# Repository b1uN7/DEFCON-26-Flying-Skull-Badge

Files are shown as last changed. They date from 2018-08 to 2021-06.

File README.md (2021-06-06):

DEFCON 26 Flying Skull Badge

__Let's wotk together for DEFCON 29 (2021)!!  I have set up a new Slack fir us to prepare: 
https://join.slack.com/t/flyingbadgers/shared_invite/zt-rhldgde9-1GLsEr0Yzdh6VICE2oVjuQ__

/------------------------------------------------------------------------------------------------\\ 

| . .  . * READ ME * . . . * NO SHIT READ ME * . . . *You will be F#@KED if you don't READ ME!!!*  . . . |

/------------------------------------------------------------------------------------------------\\ 

|--------------------__I have figured the following items out _the hard way_!!!__-----------------------|

/------------------------------------------------------------------------------------------------\\ 

| 1 DO NOT CROSS NEG & POS -/+ there is no protection for this (ie soldering on battery leads!) 

| 2 DO NOT solder RED FCU Board more then 3 SECS!  Diods will POP & NEED TO BUY NEW ONES!

| 3 If RED FCU Board from Syma 5X is solid RED (no blink) when powered see #2!!

| 4 Propellors are different (A & B) be sure to MATCH them to the MOTORS (See badge around motors!)

/------------------------------------------------------------------------------------------------\\

*** QUICK UPDATE: GETTING STARTED WITH YOU BADGE ***                   

*** (AKA GETTING YOUR BADGE STARTED) VIDEO IS NOW POSTED TO WIKI ***

Ok, so if you are here, you are probably looking for flying badge stuff like "how the f*$K do I put this thing together" or "it won't stop bliking, why won't it stop blinking"

This site (in time) will answer all those questions.

For now, until I can get stuff up on Thursday (I won't commit to which Thursday I am talking about) here are the answers to those questions:

Q1: How to put it together?

A1: If you are a hacker, figure it out!  If you are not a hacker, why the f*%K do you have a hacker badge? 

Q2: How do I get this stupid-ass badge to stop blinking?

A2: See Q1

Ok, only kidding.  If you don't have a sense of humor and you expect everything to be perfect, then "this is not the badge you are looking for" <virtual hand swipe>

If you are here, then you probably know me enough to realize if it took me a year longer to get you your badge, then you will have figured out I am behind on the documentation (*WHAT, you say, I DIDN'T DO THE DOCUMENTATION FIRST OR ALONG THE WAY???  WTF???)

So be patient and lets work together.  I will be using this repository's wiki to post a lot of the stuff you are looking for (build instructions, videos, my home address so you can come kick me in the balls for making this stupid badge, etc).  As we are a hacker community, it would be great if we worked together and post all our combined shit there!  PLEASE be and ACTIVE part of this process!!  I encourage you to post, advise, answer, and collectively curse at me for doing this to you!!

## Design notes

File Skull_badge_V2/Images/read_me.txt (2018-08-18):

Place 3D renders of the PCB and other images here

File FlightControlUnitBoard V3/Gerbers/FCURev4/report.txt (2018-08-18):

Info: Front side (top side) place file: "/Users/rscote/Dropbox/DC26/FlyingSkull/gitlab/FlightControlUnitBoard V3/Gerbers/FCURev4/FlightControlUnitBoard-top.pos".
Info: Component count: 4.
Info: Back side (bottom side) place file: "/Users/rscote/Dropbox/DC26/FlyingSkull/gitlab/FlightControlUnitBoard V3/Gerbers/FCURev4/FlightControlUnitBoard-bottom.pos".
Info: Component count: 4.
Info: Full component count: 8

Component Placement File generation OK.

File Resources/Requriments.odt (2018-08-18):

So here is a summary of what we talked about today:

Requirements:

1) AVR so mini or pro, what ever you think will work best

2) must have USB port for plug and play/programming with arduino

3) Need to dedicate a pin for each of the following:

- LEDs (one pin) for ws2812b RGB LEDS

- Sound (one pin to piezo)

- One pin with voltage divider for monitoring battery

- 6 buttons, one pin, with a series of resisters to analog read to determine button pushed

Header Pins for normal UNO for shields (8&6 and 8&10)

- 10 pin header socket for flight control board

- 10 pin header socket for LCD

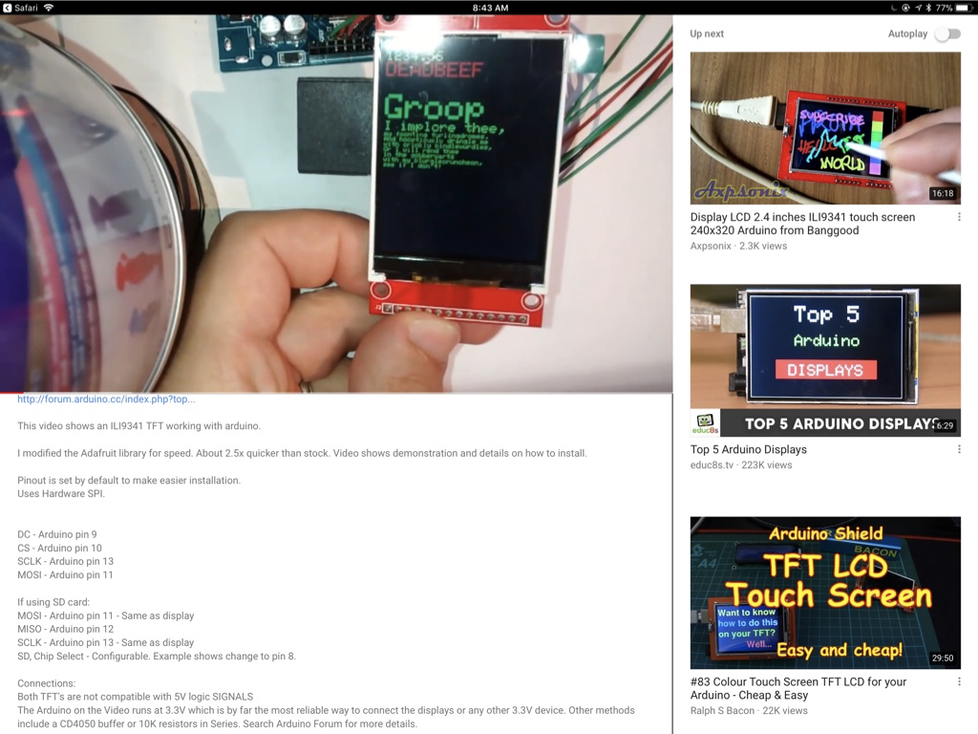
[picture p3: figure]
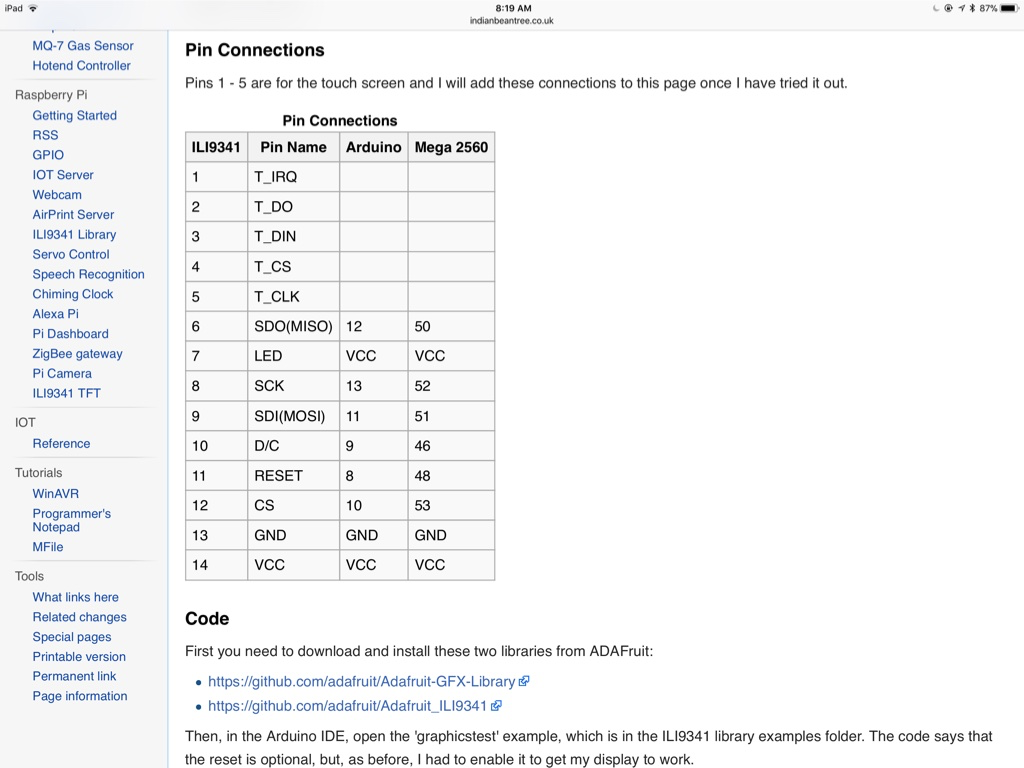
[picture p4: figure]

I will be swapping pins on LCD to the front side for mounting from behind on the skull badge, so we need to pay special attention to the pin order

battery will be a 2S LIPO so approx 8.5 v

switch to turn off Vin to badge, but NOT to the flight control header pins (so the user can turn off the lights and sound, but still fly; Vin should split and go to the switch to the voltage regulators and Vin header socket for flight control)

************************************************************

for information on the RGB LEDS see the sheet from this years attempt of mine at redoing the badge, will have sheets on them and the sound

as well as the flight control sockets

the LCD socket is new

Arduino socket libs: https://github.com/Alarm-Siren/arduino-kicad-library

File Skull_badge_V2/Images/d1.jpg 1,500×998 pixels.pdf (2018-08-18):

d1.jpg 1,500×998 pixels.pdf (https://s3.amazonaws.com/fiverr.com/message_attachements/539292386/original/d1.jpg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)
Saved to Dropbox • Jun 17, 2018 at 8B02 AM

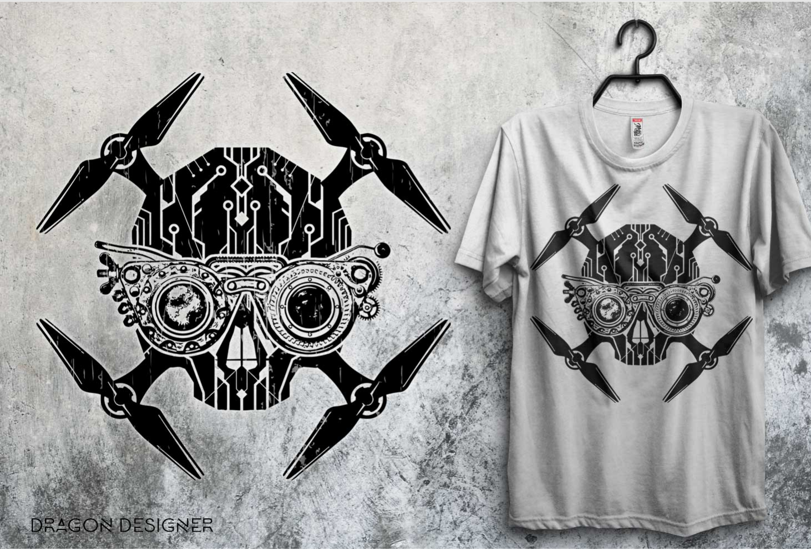
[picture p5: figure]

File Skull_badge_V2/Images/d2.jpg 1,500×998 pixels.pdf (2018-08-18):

d2.jpg 1,500×998 pixels.pdf (https://s3.amazonaws.com/fiverr.com/message_attachements/539292387/original/d2.jpg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)
Saved to Dropbox • Jun 17, 2018 at 8B02 AM

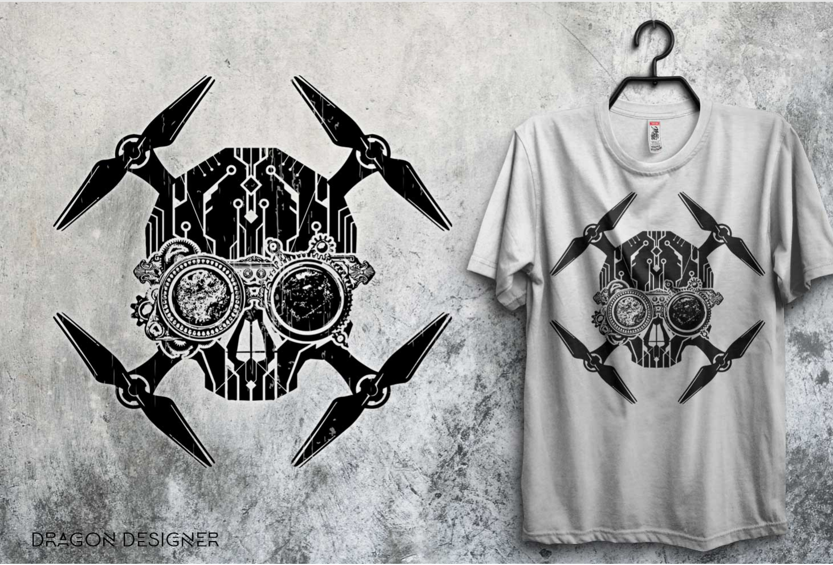
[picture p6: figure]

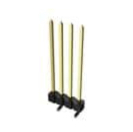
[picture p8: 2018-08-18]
Addon_board/images/95293-101-10LF Amphenol FCI Mouser 2018-07-03 07-41-04.jpg

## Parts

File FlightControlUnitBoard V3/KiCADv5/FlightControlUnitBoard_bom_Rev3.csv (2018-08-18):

Component | Description | Part | References | Value | Footprint | Quantity Per PCB | Datasheet
1 | LED generic | LED | D1 D4 | GREEN | LED_0805 | 2
2 | LED generic | LED | D2 D3 | RED | LED_0805 | 2
3 | Generic connector, single row, 01x02 | Conn_01x02_Male | J2 J3 J4 J5 J6 | Conn_01x02_Male | Wire_Pads_1x2_4x3mm | 5
4 | Generic connector, double row, 02x01, this symbol is compatible with counter-clockwise, top-bottom and odd-even numbering schemes. | Conn_02x01 | J10 J11 | Conn_02x01 | SMD_Pads_1x2 | 2
5 | Generic connector, double row, 02x01, this symbol is compatible with counter-clockwise, top-bottom and odd-even numbering schemes. | Conn_02x01 | J7 J8 J9 | Conn_02x01 | Pin_Header_Straight_1x02_Pitch2.54mm | 3
6 | Generic connector, double row, 02x05, odd/even pin numbering scheme (row 1 odd numbers, row 2 even numbers) | Conn_02x05_Odd_Even | J1 | Conn_02x05_Odd_Even | Pin_Header_Straight_2x05_Pitch2.54mm | 1
7 | Resistor | R | R1 R2 R3 R4 | 33 | R_0805 | 4
Component Groups: | 7
Component Count: | 19
Fitted Components: | 19
Number of PCBs: | 1
Total components: | 19
Schematic Version: | 0
Schematic Date: | 4/24/18
BoM Date: | Friday, June 29, 2018 'PMt' 12:47:06 PM
Schematic Source: | /Users/rscote/Dropbox/DC26/FlyingSkull/gitlab/FlightControlUnitBoard V3/FlightControlUnitBoard.sch
KiCad Version: | Eeschema 4.0.7

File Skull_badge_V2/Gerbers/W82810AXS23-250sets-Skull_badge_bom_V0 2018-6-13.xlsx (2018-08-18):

Component | Description | Part | References | Value | Footprint | Quantity Per PCB | Datasheet | manf# | 250sets
1 |  | C_Small | C4 C6 C14 C15 C16 C17 C18 C19 C20 C21 C22 C23 C24 C25 C26 C27 C28 C29 C30 | 100nF | C_0805 | 19 |  | Use house parts |  |  | house 0805 capacitors are fine
2 |  | C_Small | C1 C7 C12 C13 | 10uF | C_0805 | 4 |  | Use house parts | $0.055 | $0.220
3 |  | C_Small | C5 C8 C9 C10 C11 | 1uF | C_0805 | 5 |  | Use house parts | $0.055 | $0.275
4 |  | C_Small | C2 C3 | 22pF | C_0805 | 2 |  | Use house parts | $0.009 | $0.018
5 |  | LED | D4 | L | LED_0805 | 1 |  | Use house parts | $0.187 | $0.187
6 |  | LED | D3 | PWR | LED_0805 | 1 |  | Use house parts | $0.187 | $0.187
7 |  | LED | D1 | RX | LED_0805 | 1 |  | Use house parts | $0.187 | $0.187
8 |  | LED | D2 | TX | LED_0805 | 1 |  | Use house parts | $0.187 | $0.187
9 |  | Fuse | F1 | Fuse | Fuse_SMD2920 | 1 |  | 2920L500/16MR | $1.562 | $1.562 | Do you have an equal house part?
10 |  | Conn_01x02 | J4 | BtmL | Wire_Pads_1x2_4x3mm_Extended | 1 |  | Do Not Source, Nothing to Assemble, Leave Empty |  |  | DNS
11 |  | Conn_01x02 | J5 | BtmR | Wire_Pads_1x2_4x3mm_Extended | 1 |  | Do Not Source, Nothing to Assemble, Leave Empty |  |  | DNS
12 |  | Conn_02x05 | J7 | Flight Controller Board | Socket_Strip_Straight_2x05_Pitch2.54mm | 1 |  |  | $0.110 | $0.110 | 2*5pin 2.54mm pls check the pic
13 |  | Conn_01x02 | J2 | LiPo | JST_PH_S2B-PH-K_02x2.00mm_Angled | 1 |  | IF you cannot find a PCB mount option then DNS | $0.088 | $0.088 | ~~S2B-PH-K-S(LF)(SN)~~ | LOSI Female PCB Mount | 51005-Micro-losi-connecto
14 |  | Conn_01x03 | J8 | SPI | Pin_Header_Straight_1x03_Pitch2.54mm | 1 |  |  | $0.022 | $0.022 | pin header 1*3pin 2.54mm
15 |  | Conn_01x02 | J6 | TopL | Wire_Pads_1x2_4x3mm_Extended | 1 |  | Do Not Source, Nothing to Assemble, Leave Empty |  |  | DNS
16 |  | Conn_01x02 | J3 | TopR | Wire_Pads_1x2_4x3mm_Extended | 1 |  | Do Not Source, Nothing to Assemble, Leave Empty |  |  | DNS
17 |  | USB_OTG | J1 | USB_OTG | USB_Micro-B_10103594-0001LF | 1 |  | 10103594-0001LF | $0.462 | $0.462
18 |  | L | L2 | 2.2uH | VLF4012A | 1 |  | VLF4012AT-2R2M1R5 | $0.385 | $0.385
19 |  | L | L1 | L | L_0805 | 1 |  | BLM21AG601SN1D | $0.033 | $0.033
20 |  | Speaker_Crystal | LS1 | piezo_KJL_1325 | https://lcsc.com/product-detail/Buzzers_KELIKING-KLJ-1325_C201043.html | 1 |  | https://datasheet.lcsc.com/szlcsc/KELIKING-KLJ-1325_C201043.pdf | $0.590 | $0.590 | http://www.keliking.com/KLJ-1325-SMD-Piezo-Buzzer-pd6794765.html
21 |  | R | R5 | 100 | R_0805 | 1 |  | Use house parts | $0.009 | $0.009
22 |  | R | R3 R6 | 10K | R_0805 | 2 |  | Use house parts | $0.009 | $0.018
23 |  | R | R7 R8 R9 R12 R13 R14 R15 R16 R17 R18 R19 | 1K | R_0805 | 11 |  | Use house parts | $0.009 | $0.097
24 |  | R | R4 R10 R20 | 1M | R_0805 | 3 |  | Use house parts | $0.009 | $0.026
25 |  | R | R1 R2 | 22 | R_0805 | 2 |  | Use house parts | $0.009 | $0.018
26 |  | R | R11 | 2M | R_0805 | 1 |  | Use house parts | $0.009 | $0.009
27 |  | R | R21 | 300 | R_0805 | 1 |  | RC0805JR-07300RL | $0.009 | $0.009
28 |  | SW_SPDT | SW2 | ARD_SW | switch_MSK-12D19 | 1 |  | MSK-12D19 | $0.050 | $0.050 | Aliexpress $0.05/ea https://www.aliexpress.com/item/FREE-SHIPPING-100pcs-lot-MSK-12D19-1P2T-3PIN-toggle-switch-micro-switch-slide-switch/32770997921.html
29 |  | SW_SPDT | SW3 | FLT CTRL SW | switch_MSK-12D19 | 1 |  | MSK-12D19 | $0.050 | $0.050 | Aliexpress $0.05/ea https://www.aliexpress.com/item/FREE-SHIPPING-100pcs-lot-MSK-12D19-1P2T-3PIN-toggle-switch-micro-switch-slide-switch/32770997921.html
30 |  | SW_Push | SW1 | RESET | smd_push | 1 |  |  | $0.030 | $0.030 | Aliexpress $0.0.3/ea https://www.aliexpress.com/item/1000-Pcs-Per-Lot-Momentary-Tactile-Tact-Push-Button-Switch-2-Pin-SMD-SMT-3x6x2-5mm/32261460144.html
31 |  | SW_Push | SW4 SW5 SW6 SW7 SW8 SW9 | SW_Push | smd_push | 6 |  |  | $0.030 | $0.180 | Aliexpress $0.0.3/ea https://www.aliexpress.com/item/1000-Pcs-Per-Lot-Momentary-Tactile-Tact-Push-Button-Switch-2-Pin-SMD-SMT-3x6x2-5mm/32261460144.html
32 | TQFP44, 16K Flash, 1.25K SRAM, 512B EEPROM, USB2.0 | ATMEGA32U4-AU | U1 | ATMEGA32U4-AU | TQFP-44_10x10mm_Pitch0.8mm | 1 | http://www.atmel.com/images/atmel-7766-8-bit-avr-atmega16u4-32u4_%20datasheet.pdf | ATMEGA32U4-AUR | $3.520 | $3.520
33 |  | TPS63001 | U2 | TPS63001 | VSON-10-1EP_3x3mm_Pitch0.5mm_ThermalPad | 1 |  | TPS63002DRCT | $1.430 | $1.430
34 |  | WS2812B | U9 U10 U11 U12 U13 U14 U15 U16 U17 U18 U19 U20 U21 U22 U23 U24 | WS2812B | LED_WS2812B-PLCC4 | 16 |  | 1655 | $0.060 | $0.968 | aliexpress: $.06/ea https://www.aliexpress.com/item/WS2812B-4pins-5050-SMD-W-WS2811-Individually-Addressable-Digital-RGB-LED-Chip-5V/1639139960.html
35 |  | Conn_02x02 | X1 | Badgelife_shitty_connector | Socket_Strip_Straight_2x02_Pitch2.54mm | 1 |  |  |  |  | aliexpress $.05/ea https://www.aliexpress.com/item/100pcs-2x2-Pin-2-54mm-Double-Row-Female-Pin-Header-4P-PCB-Socket-Connector/32604467904.html
36 |  | Conn_01x06 |  | 1x6 socket strip 2.54mm |  | 1 |  |  |  |  | strip for arduino uno socket headers
37 |  | Conn_01x10 |  | 1x10 scoket strip 2.54mm |  | 1 |  |  |  |  | strip for arduino uno socket headers
38 |  | Conn_01x08 |  | 1x8 scoket strip 2.54mm |  | 2 |  |  |  |  | strip for arduino uno socket headers
39 |  | Header Pins 02x03 | XA1 | 2x3 Header Pins 2.54mm |  | 1 |  |  |  |  | ICSP Arduino Uno Header Pins
40 |  | Crystal | Y1 | 16MHz | Q_49U3HMS | 1 |  | ABLS-16.000MHZ-B4-T | $0.220 | $0.220 | Do you have an equal house part?
41 |  | Regulator voltage 3v3 |  | 1117-3v3 |  | 1 |  |  | 1 set | $11.145
 |  |  |  |  |  |  |  |  | 250 sets | $2786.350 | http://www.irf.com/product-info/datasheets/data/iru1117-33.pdf
Component Groups: | 41
Component Count: | 99
Fitted Components: | 99
Number of PCBs: | 1
Total components: | 99
Schematic Version: | V0
Schematic Date: | 5/14/18
BoM Date: | Monday, June 11, 2018 'PMt' 04:22:07 PM
Schematic Source: | /Users/rscote/Dropbox/DC26/FlyingSkull/gitlab/Skull_badge_V2/Skull_badge.sch
KiCad Version: | Eeschema 4.0.7
J7 |  |  | J2
 |  |  |  |  |  | LS1
SW2 SW3
 |  |  | s1,s4,s5,s6,s7,s8,s9

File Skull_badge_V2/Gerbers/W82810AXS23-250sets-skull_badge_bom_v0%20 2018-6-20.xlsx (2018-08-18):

Component | Description | Part | References | Value | Footprint | Quantity Per PCB | Datasheet | manf# |  |  |  | 250sets
1 |  | C_Small | C4 C6 C14 C15 C16 C17 C18 C19 C20 C21 C22 C23 C24 C25 C26 C27 C28 C29 C30 | 100nF | C_0805 | 19 |  | Use house parts | house 0805 capacitors are fine |  |  | $0.033 | $0.627
2 |  | C_Small | C1 C7 C12 C13 | 10uF | C_0805 | 4 |  | Use house parts |  |  |  | $0.055 | $0.220
3 |  | C_Small | C5 C8 C9 C10 C11 | 1uF | C_0805 | 5 |  | Use house parts |  |  |  | $0.055 | $0.275
4 |  | C_Small | C2 C3 | 22pF | C_0805 | 2 |  | Use house parts |  |  |  | $0.009 | $0.018
5 |  | LED 0805 GREEN | D4 | L | LED_0805 | 1 |  | Use house parts |  |  |  | $0.187 | $0.187 | 5-7work days
6 |  | LED 0805 BLUE | D3 | PWR | LED_0805 | 1 |  | Use house parts |  |  |  | $0.187 | $0.187 | 5-7work days
7 |  | LED 0805 WHITE | D1 | RX | LED_0805 | 1 |  | Use house parts |  |  |  | $0.187 | $0.187 | 5-7work days
8 |  | LED 0805 WHITE | D2 | TX | LED_0805 | 1 |  | Use house parts |  |  |  | $0.187 | $0.187 | 5-7work days
9 |  | Fuse | F1 | Fuse | Fuse_SMD2920 | 1 |  | 2920L500/16MR | Do you have an equal house part? |  |  | $0.385 | $0.385 | Made in China
10 |  | Conn_01x02 | J4 | BtmL | Wire_Pads_1x2_4x3mm_Extended | 1 |  | Do Not Source, Nothing to Assemble, Leave Empty | DNS
11 |  | Conn_01x02 | J5 | BtmR | Wire_Pads_1x2_4x3mm_Extended | 1 |  | Do Not Source, Nothing to Assemble, Leave Empty | DNS
12 |  | Conn_02x05 | J7 | Flight Controller Board | Socket_Strip_Straight_2x05_Pitch2.54mm | 1 |  |  | 2*5pin 2.54mm pls check the pic |  |  | $0.110 | $0.110 | 2*5pin 2.54mm pls check the pic
13 |  | Conn_01x02 | J2 | LiPo | JST_PH_S2B-PH-K_02x2.00mm_Angled | 1 |  | Do Not Source, Nothing to Assemble, Leave Empty | DNS | LOSI Female PCB Mount | 51005-Micro-losi-connecto
14 |  | Conn_01x03 | J8 | SPI | Pin_Header_Straight_1x03_Pitch2.54mm | 1 |  |  | pin header 1*3pin 2.54mm |  |  | $0.022 | $0.022 | pin header 1*3pin 2.54mm
15 |  | Conn_01x02 | J6 | TopL | Wire_Pads_1x2_4x3mm_Extended | 1 |  | Do Not Source, Nothing to Assemble, Leave Empty | DNS
16 |  | Conn_01x02 | J3 | TopR | Wire_Pads_1x2_4x3mm_Extended | 1 |  | Do Not Source, Nothing to Assemble, Leave Empty | DNS
17 |  | USB_OTG | J1 | USB_OTG | USB_Micro-B_10103594-0001LF | 1 |  | 10103594-0001LF |  |  |  | $0.462 | $0.462
18 |  | L | L2 | 2.2uH | VLF4012A | 1 |  | VLF4012AT-2R2M1R5 |  |  |  | $0.385 | $0.385
19 |  | L | L1 | L | L_0805 | 1 |  | BLM21AG601SN1D |  |  |  | $0.033 | $0.033
20 |  | Speaker_Crystal | LS1 | piezo_KJL_1325 | https://lcsc.com/product-detail/Buzzers_KELIKING-KLJ-1325_C201043.html | 1 |  | https://datasheet.lcsc.com/szlcsc/KELIKING-KLJ-1325_C201043.pdf | http://www.keliking.com/KLJ-1325-SMD-Piezo-Buzzer-pd6794765.html |  |  | $0.770 | $0.770 | KLJ-1325 SMD 1 week order time
21 |  | R | R5 | 100 | R_0805 | 1 |  | Use house parts |  |  |  | $0.009 | $0.009
22 |  | R | R3 R6 | 10K | R_0805 | 2 |  | Use house parts |  |  |  | $0.009 | $0.018
23 |  | R | R7 R8 R9 R12 R13 R14 R15 R16 R17 R18 R19 | 1K | R_0805 | 11 |  | Use house parts |  |  |  | $0.009 | $0.097
24 |  | R | R4 R10 R20 | 1M | R_0805 | 3 |  | Use house parts |  |  |  | $0.009 | $0.026
25 |  | R | R1 R2 | 22 | R_0805 | 2 |  | Use house parts |  |  |  | $0.009 | $0.018
26 |  | R | R11 | 2M | R_0805 | 1 |  | Use house parts |  |  |  | $0.009 | $0.009
27 |  | R | R21 | 300 | R_0805 | 1 |  | RC0805JR-07300RL |  |  |  | $0.009 | $0.009
28 |  | SW_SPDT | SW2 | ARD_SW | SW_SPDT_PCM12 | 1 |  | MSK-12C02 | Aliexpress $0.03/ea https://www.aliexpress.com/item/50Pcs-Mini-7-Pin-On-Off-1P2T-SPDT-MSK-12C02-SMD-Toggle-Slide-Switch-For-MP3/32839604589.html |  |  | $0.030 | $0.030 | Made in China, MSK-12D19
30 |  | SW_Push | SW1 | RESET | smd_push | 1 |  |  | Aliexpress $0.0.3/ea https://www.aliexpress.com/item/1000-Pcs-Per-Lot-Momentary-Tactile-Tact-Push-Button-Switch-2-Pin-SMD-SMT-3x6x2-5mm/32261460144.html |  |  | $0.033 | $0.033 | Made in China
31 |  | SW_Push | SW4 SW5 SW6 SW7 SW8 SW9 | SW_Push | smd_push | 6 |  |  | Aliexpress $0.0.3/ea https://www.aliexpress.com/item/1000-Pcs-Per-Lot-Momentary-Tactile-Tact-Push-Button-Switch-2-Pin-SMD-SMT-3x6x2-5mm/32261460144.html |  |  | $0.033 | $0.198 | Made in China
32 | TQFP44, 16K Flash, 1.25K SRAM, 512B EEPROM, USB2.0 | ATMEGA32U4-AU | U1 | ATMEGA32U4-AU | TQFP-44_10x10mm_Pitch0.8mm | 1 | http://www.atmel.com/images/atmel-7766-8-bit-avr-atmega16u4-32u4_%20datasheet.pdf | ATMEGA32U4-AUR |  |  |  | $3.520 | $3.520
33 |  | TPS63001 | U2 | TPS63001 | VSON-10-1EP_3x3mm_Pitch0.5mm_ThermalPad | 1 |  | TPS63002DRCT |  |  |  | $1.430 | $1.430
34 |  | WS2812B | U9 U10 U11 U12 U13 U14 U15 U16 U17 U18 U19 U20 U21 U22 U23 U24 | WS2812B | LED_WS2812B-PLCC4 | 16 |  | 1655 | aliexpress: $.06/ea https://www.aliexpress.com/item/WS2812B-4pins-5050-SMD-W-WS2811-Individually-Addressable-Digital-RGB-LED-Chip-5V/1639139960.html |  |  | $0.110 | $1.760 | WS2812B SMD4 size 5050 | 贴片前75度 除湿48小时，焊接温度不超过250摄氏度-徐冰雪购买
35 |  | Conn_02x02 | X1 | Badgelife_shitty_connector | Socket_Strip_Straight_2x02_Pitch2.54mm | 1 |  |  | aliexpress $.05/ea https://www.aliexpress.com/item/100pcs-2x2-Pin-2-54mm-Double-Row-Female-Pin-Header-4P-PCB-Socket-Connector/32604467904.html |  |  | $0.066 | $0.066 | pin female 2*2pin 2.54mm height 8.5mm
36 |  | Conn_01x06 |  | 1x6 socket strip 2.54mm |  | 1 |  |  | strip for arduino uno socket headers |  |  | $0.022 | $0.022 | pin header 1*6pin 2.54mm
37 |  | Conn_01x10 |  | 1x10 scoket strip 2.54mm |  | 1 |  |  | strip for arduino uno socket headers |  |  | $0.033 | $0.033 | pin header 1*10pin 2.54mm
38 |  | Conn_01x08 |  | 1x8 scoket strip 2.54mm |  | 2 |  |  | strip for arduino uno socket headers |  |  | $0.033 | $0.066 | pin header 1*8pin 2.54mm
39 |  | Header Pins 02x03 | XA1 | 2x3 Header Pins 2.54mm |  | 1 |  |  | DNS |  |  | $0.033 | $0.033 | pin header 2*3pin 2.54mm
40 |  | Crystal | Y1 | 16MHz | Q_49U3HMS | 1 |  | ABLS-16.000MHZ-B4-T | Do you have an equal house part? |  |  | $0.088 | $0.088 | Made in China
41 |  | Regulator voltage 3v3 |  | 1117-3v3 |  | 1 |  |  |  |  |  | $0.099 | $0.099 | offer is AMS1117-3.3 SOT223
 |  |  |  |  |  |  |  |  | http://www.irf.com/product-info/datasheets/data/iru1117-33.pdf |  |  | 1 set | $11.62
 |  |  |  |  |  |  |  |  |  |  |  | 300 sets | $3485.22
Component Groups: | 41
Component Count: | 99
Fitted Components: | 99
Number of PCBs: | 1
Total components: | 99
Schematic Version: | V0
Schematic Date: | 5/14/18
BoM Date: | Monday, June 11, 2018 'PMt' 04:22:07 PM
Schematic Source: | /Users/rscote/Dropbox/DC26/FlyingSkull/gitlab/Skull_badge_V2/Skull_badge.sch
KiCad Version: | Eeschema 4.0.7
J7
 |  |  |  |  |  | LS1
SW2
 |  |  | s1,s4,s5,s6,s7,s8,s9

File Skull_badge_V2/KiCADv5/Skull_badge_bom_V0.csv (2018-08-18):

Component | Description | Part | References | Value | Footprint | Quantity Per PCB | Datasheet | manf#
1 |  | C_Small | C4 C6 C14 C15 C16 C17 C18 C19 C20 C21 C22 C23 C24 C25 C26 C27 C28 C29 C30 | 100nF | C_0805 | 19 |  | 885012207053 885012207060 885012207049 885012207045 885012207056 885012207046 885012207050 885012207057 885012207047 885012207051 885012207054 885012207058 885012207048 885012207052 885012207055 885012207059
2 |  | C_Small | C1 C7 C12 C13 | 10uF | C_0805 | 4
3 |  | C_Small | C5 C8 C9 C10 C11 | 1uF | C_0805 | 5
4 |  | C_Small | C2 C3 | 22pF | C_0805 | 2
5 |  | LED | D4 | L | LED_0805 | 1 |  | 150080YS75000
6 |  | LED | D3 | PWR | LED_0805 | 1 |  | 150080YS75000
7 |  | LED | D1 | RX | LED_0805 | 1 |  | 150080YS75000
8 |  | LED | D2 | TX | LED_0805 | 1 |  | 150080YS75000
9 |  | Fuse | F1 | Fuse | Fuse_SMD2920 | 1 |  | 2920L500/16MR
10 |  | Conn_01x02 | J4 | BtmL | Wire_Pads_1x2_4x3mm_Extended | 1
11 |  | Conn_01x02 | J5 | BtmR | Wire_Pads_1x2_4x3mm_Extended | 1
12 |  | Conn_02x05 | J7 | Flight Controller Board | Socket_Strip_Straight_2x05_Pitch2.54mm | 1
13 |  | Conn_01x02 | J2 | LiPo | JST_PH_S2B-PH-K_02x2.00mm_Angled | 1
14 |  | Conn_01x03 | J8 | SPI | Pin_Header_Straight_1x03_Pitch2.54mm | 1
15 |  | Conn_01x02 | J6 | TopL | Wire_Pads_1x2_4x3mm_Extended | 1
16 |  | Conn_01x02 | J3 | TopR | Wire_Pads_1x2_4x3mm_Extended | 1
17 |  | USB_OTG | J1 | USB_OTG | USB_Micro-B_10103594-0001LF | 1 |  | 10103594-0001LF
18 |  | L | L2 | 2.2uH | VLF4012A | 1 |  | VLF4012AT-2R2M1R5
19 |  | L | L1 | L | L_0805 | 1 |  | BLM21AG601SN1D
20 |  | Speaker_Crystal | LS1 | Speaker_Crystal | piezo_KJL_1325 | 1 |  | KLJ-1325
21 |  | R | R5 | 100 | R_0805 | 1
22 |  | R | R3 R6 | 10K | R_0805 | 2
23 |  | R | R7 R8 R9 R12 R13 R14 R15 R16 R17 R18 R19 | 1K | R_0805 | 11
24 |  | R | R4 R10 R20 | 1M | R_0805 | 3
25 |  | R | R1 R2 | 22 | R_0805 | 2
26 |  | R | R11 | 2M | R_0805 | 1
27 |  | R | R21 | 300 | R_0805 | 1 |  | RC0805JR-07300RL
28 |  | SW_SPDT | SW2 | ARD_SW | switch_MHSS1105 | 1 |  | MHSS1105
29 |  | SW_SPDT | SW3 | FLT CTRL SW | switch_MHSS1105 | 1 |  | MHSS1105
30 |  | SW_Push | SW1 | RESET | smd_push | 1 |  | MJTP1106STR
31 |  | SW_Push | SW4 SW5 SW6 SW7 SW8 SW9 | SW_Push | smd_push | 6 |  | MJTP1106STR
32 | TQFP44, 16K Flash, 1.25K SRAM, 512B EEPROM, USB2.0 | ATMEGA32U4-AU | U1 | ATMEGA32U4-AU | TQFP-44_10x10mm_Pitch0.8mm | 1 | http://www.atmel.com/images/atmel-7766-8-bit-avr-atmega16u4-32u4_%20datasheet.pdf | ATMEGA32U4-AUR
33 |  | TPS63001 | U2 | TPS63001 | VSON-10-1EP_3x3mm_Pitch0.5mm_ThermalPad | 1 |  | TPS63002DRCT
34 |  | WS2812B | U9 U10 U11 U12 U13 U14 U15 U16 U17 U18 U19 U20 U21 U22 U23 U24 | WS2812B | LED_WS2812B-PLCC4 | 16 |  | 1655
35 |  | Conn_02x02 | X1 | Badgelife_shitty_connector | Socket_Strip_Straight_2x02_Pitch2.54mm | 1
36 |  | Arduino_Uno_Shield | XA1 | Arduino_Uno_Shield | UNO_headersICSP: (2) Socket_Strip 1x08, (1) Socket_Strip 1x06, (1) Socket_Strip 1x10, (1) Header_Pins 02x03 | 1
37 |  | Crystal | Y1 | 16MHz | Q_49U3HMS | 1 |  | ABLS-16.000MHZ-B4-T
Component Groups: | 39
Component Count: | 99
Fitted Components: | 99
Number of PCBs: | 1
Total components: | 99
Schematic Version: | V0
Schematic Date: | 5/14/18
BoM Date: | Monday, June 11, 2018 'PMt' 04:22:07 PM
Schematic Source: | /Users/rscote/Dropbox/DC26/FlyingSkull/gitlab/Skull_badge_V2/Skull_badge.sch
KiCad Version: | Eeschema 4.0.7

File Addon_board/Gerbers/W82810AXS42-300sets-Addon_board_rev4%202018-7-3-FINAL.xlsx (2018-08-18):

Id | Designator | Package | Quantity | Designation | Supplier and ref |  | 300sets
1 | C5 | C_0805 | 1 | 10 pF |  |  |  |  | offer the parameter
2 | J1 | Pin_Header_Straight_1x03_Pitch2.54mm | 1 | SPI |  |  | $0.022 | $0.022 | pin header 1*3pin 2.54mm
3 | C6,C7 | C_0805 | 2 | 0.1uF |  |  | $0.033 | $0.066
4 | D1 | LED_0805 | 1 | LED |  |  | $0.022 | $0.022 | LED 0805 green,made in China
5 | R1,R2,R5,R6 | R_0805 | 4 | 10K |  |  | $0.009 | $0.035
6 | R3 | R_0805 | 1 | 1K |  |  | $0.009 | $0.009
7 | R4 | R_0805 | 1 | 2K |  |  | $0.009 | $0.009
8 | U4 | SOIC-8_3.9x4.9mm_Pitch1.27mm | 1 | 24LC256 |  |  | $0.352 | $0.352 | complete part number is 24LC256T-I/SN
9 | U5 | TSSOP-20_4.4x6.5mm_Pitch0.65mm | 1 | TXB0108PWR |  |  | $0.792 | $0.792
10 | U2 | DCDC_BOOST | 1 | DD06AJSA |  |  |  |  | DNS
16 | J4 | SolderJumper | 1 | GS2 | DNS |  |  |  | DNS
17 | SW1,SW2,SW3 | MSK12C02 | 3 | SW_SPDT |  |  | $0.044 | $0.132 | MSK-12C02,made in China
19 | XA2 | UNO_headersICSP_EDIT_10smd | 1 | Shield |  |  |  |  | PARTS LISTED BELOW spreadsheet lines 15-18
 | XA2 Parts
 | X2A - 1X6 | 1x6_Long_pin_Stackable_header Socket | 1 |  |  |  | $0.022 | $0.022 | pin header 1*6pin 2.54mm | MUST BE LONG PIN STACKABLE
 | X2A-1X8 | 1x8_Long_pin_Stackable_header Socket | 2 |  |  |  | $0.022 | $0.044 | pin header 1*8pin 2.54mm | MUST BE LONG PIN STACKABLE
 | X2A 1X10 | 1x10_SMD_header Socket | 1 |  |  |  | $0.033 | $0.033 | pin header 1*10pin 2.54mm | MUST BE LONG PIN STACKABLE
 | J2 | 1x10_SMD_Long_Header_Pins | 1 | pn 95293-101-10LF mouser has them in stock IM 1X10 |  |  | $1.947 | $0.900 | 95293-101-10LF 1*10 PIN LONG 5-7work days | CAN BE CHINESE MADE IF YOU CAN SOURCE SMD LONG PIN HEADERS
 |  |  |  |  |  |  | 1 set | $2.438
 |  |  |  |  |  |  | 300 sets | $731.34
 | X2A - 1X6, 1x8, LONG PINS |  | X2A 1X10 SMD |  |  | J2

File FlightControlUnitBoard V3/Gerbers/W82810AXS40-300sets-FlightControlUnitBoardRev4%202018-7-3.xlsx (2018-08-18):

Id | Designator | Package | Quantity | Designation | Supplier and ref | 300sets
1 | LED1,LED4 | LED_0805 | 2 | GREEN |  | $0.022 | $0.044 | LED 0805 green,made in China
2 | R1,R4 | R_0805 | 2 | 33 |  | $0.009 | $0.018
3 | LED2,LED3 | LED_0805 | 2 | RED |  | $0.022 | $0.044 | LED 0805 red,made in China
4 | R2,R3 | R_0805 | 2 | 47 |  | $0.009 | $0.018
5 | J10,J11 | Pin_Header_Straight_1x02 | 2 | Pin_Header_Straight_1x02 |  | $0.011 | $0.022 | pin heade 1*2pin 2.54m
10 | J5,J6,J2,J4,J3,J2,J3,J4,J5,J6 | Wire_Pads_1x2_4x3mm | 10 | Conn_01x02_Male | DNS
11 | J1 | Pin_Header_Straight_2x05_Pitch2.54mm | 1 | Conn_02x05_Odd_Even |  | $0.044 | $0.044 | pin header 2*5pin 2.54mm
12 | J9,J8,J7 | Pin_Header_Straight_1x02_Pitch2.54mm | 3 | Conn_02x01 |  | $0.011 | $0.033 | pin header 1*2pin 2.54m
 |  |  |  |  |  | 1 set | $0.222
 |  |  |  |  |  | 300 sets | $66.66

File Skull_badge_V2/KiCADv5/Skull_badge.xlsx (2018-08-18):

 |  |  |  |  |  |  | Board Qty: | 100
 |  |  |  |  |  |  | Total Cost: | $748.16 |  |  |  | $748.16
 |  |  |  |  |  |  | Unit Cost: | $7.48
Global Part Info |  |  |  |  |  |  |  |  | Digi-Key
Refs | Value | Desc | Footprint | Manf | Manf# | Qty | Unit$ | Ext$ | Avail | Purch | Unit$ | Ext$ | Cat# | Doc
D4 | L |  | Skull_badge:LED_0805 |  | 150080YS75000 | 100 | $0.14 | $13.70 | 11297 |  | $0.14 | $13.70 | 732-4987-1-ND | Link (http://www.digikey.com/product-detail/en/wurth-electronics-inc/150080YS75000/732-4987-1-ND/4489925)
J5 | BtmR |  | Skull_badge:Wire_Pads_1x2_4x3mm_Extended |  |  | 100 | $0.00 | $0.00
U9-U24 | WS2812B |  | Skull_badge:LED_WS2812B-PLCC4 |  | 1655 | 1600 | $0.00 | $0.00
R1,R2 | 22 |  | Skull_badge:R_0805 |  |  | 200 | $0.00 | $0.00
R21 | 300 |  | Skull_badge:R_0805 |  | RC0805JR-07300RL | 100 | $0.01 | $0.76 | 95913 |  | $0.01 | $0.76 | 311-300ARCT-ND | Link (http://www.digikey.com/product-detail/en/yageo/RC0805JR-07300RL/311-300ARCT-ND/731254)
J4 | BtmL |  | Skull_badge:Wire_Pads_1x2_4x3mm_Extended |  |  | 100 | $0.00 | $0.00
U1 | ATMEGA32U4-AU |  | Skull_badge:TQFP-44_10x10mm_Pitch0.8mm |  | ATMEGA32U4-AUR | 100 | $3.49 | $349.17 | 13471 |  | $3.49 | $349.17 | ATMEGA32U4-AURCT-ND | Link (http://www.digikey.com/product-detail/en/microchip-technology/ATMEGA32U4-AUR/ATMEGA32U4-AURCT-ND/3440960)
C2,C3 | 22pF |  | Skull_badge:C_0805 |  |  | 200 | $0.00 | $0.00
J8 | SPI |  | Pin_Headers:Pin_Header_Straight_1x03_Pitch2.54mm |  |  | 100 | $0.00 | $0.00
SW1 | RESET |  | Skull_badge:smd_push |  | MJTP1106STR | 100 | $0.51 | $51.06 | 10429 |  | $0.51 | $51.06 | 679-2395-1-ND | Link (http://www.digikey.com/product-detail/en/apem-inc/MJTP1106STR/679-2395-1-ND/2344159)
J2 | LiPo |  | Skull_badge:JST_PH_S2B-PH-K_02x2.00mm_Angled |  |  | 100 | $0.00 | $0.00
R7-R9,R12-R19 | 1K |  | Skull_badge:R_0805 |  |  | 1100 | $0.00 | $0.00
SW3 | FLT CTRL SW |  | Skull_badge:switch_MHSS1105 |  | MHSS1105 | 100 | $0.43 | $42.80 | 18880 |  | $0.43 | $42.80 | 679-1849-ND | Link (http://www.digikey.com/product-detail/en/apem-inc/MHSS1105/679-1849-ND/1949465)
U6 | Lime_pepper |  | Skull_badge:lime_pepper |  |  | 100 | $0.00 | $0.00
LS1 | Speaker_Crystal |  | Skull_badge:piezo_KJL_1325 |  | KLJ-1325 | 100 | $0.00 | $0.00
C4,C6 | 100nF |  | Skull_badge:C_0805 |  |  | 200 | $0.00 | $0.00
D1 | RX |  | Skull_badge:LED_0805 |  | 150080YS75000 | 100 | $0.14 | $13.70 | 11297 |  | $0.14 | $13.70 | 732-4987-1-ND | Link (http://www.digikey.com/product-detail/en/wurth-electronics-inc/150080YS75000/732-4987-1-ND/4489925)
L2 | 2.2uH |  | Skull_badge:VLF4012A |  | VLF4012AT-2R2M1R5 | 100 | $0.52 | $51.75 | 48078 |  | $0.52 | $51.75 | 445-3233-1-ND | Link (http://www.digikey.com/product-detail/en/tdk-corporation/VLF4012AT-2R2M1R5/445-3233-1-ND/1132874)
R3,R6 | 10K |  | Skull_badge:R_0805 |  |  | 200 | $0.00 | $0.00
J1 | USB_OTG |  | Skull_badge:USB_Micro-B_10103594-0001LF |  | 10103594-0001LF | 100 | $0.55 | $55.03 | 64462 |  | $0.55 | $55.03 | 609-4050-1-ND | Link (http://www.digikey.com/product-detail/en/amphenol-fci/10103594-0001LF/609-4050-1-ND/2350357)
F1 | Fuse |  | Skull_badge:Fuse_SMD2920 |  | 2920L500/16MR | 100 | $1.17 | $117.12 | 15805 |  | $1.17 | $117.12 | F6136CT-ND | Link (http://www.digikey.com/product-detail/en/littelfuse-inc/2920L500-16MR/F6136CT-ND/4147146)
X1 | Badgelife_shitty_connector |  | Skull_badge:Badgelife-Shitty-2x2 |  |  | 100 | $0.00 | $0.00
C5,C8-C11 | 1uF |  | Skull_badge:C_0805 |  |  | 500 | $0.00 | $0.00
L1 | L |  | Inductors_SMD:L_0805 |  | BLM21AG601SN1D | 100 | $0.07 | $6.68 | 988892 |  | $0.07 | $6.68 | 490-1040-1-ND | Link (http://www.digikey.com/product-detail/en/murata-electronics-north-america/BLM21AG601SN1D/490-1040-1-ND/584488)
R4,R10,R20 | 1M |  | Skull_badge:R_0805 |  |  | 300 | $0.00 | $0.00
C28 | 0.1uF |  | Skull_badge:C_0805 |  | 885012207052 | 100 | $0.00 | $0.00
C14,C21 | 0.1uF |  | Skull_badge:C_0805 |  | 885012207053 | 200 | $0.00 | $0.00
C20 | 0.1uF |  | Skull_badge:C_0805 |  | 885012207050 | 100 | $0.00 | $0.00
C24 | 0.1uF |  | Skull_badge:C_0805 |  | 885012207051 | 100 | $0.00 | $0.00
C18 | 0.1uF |  | Skull_badge:C_0805 |  | 885012207056 | 100 | $0.04 | $3.59 | 2831 |  | $0.04 | $3.59 | 732-8048-1-ND | Link (http://www.digikey.com/product-detail/en/wurth-electronics-inc/885012207056/732-8048-1-ND/5454675)
C22 | 0.1uF |  | Skull_badge:C_0805 |  | 885012207057 | 100 | $0.00 | $0.00
C25 | 0.1uF |  | Skull_badge:C_0805 |  | 885012207054 | 100 | $0.00 | $0.00
C29 | 0.1uF |  | Skull_badge:C_0805 |  | 885012207055 | 100 | $0.00 | $0.00
C26 | 0.1uF |  | Skull_badge:C_0805 |  | 885012207058 | 100 | $0.00 | $0.00
C30 | 0.1uF |  | Skull_badge:C_0805 |  | 885012207059 | 100 | $0.00 | $0.00
C15 | 0.1uF |  | Skull_badge:C_0805 |  | 885012207060 | 100 | $0.00 | $0.00
C16 | 0.1uF |  | Skull_badge:C_0805 |  | 885012207049 | 100 | $0.00 | $0.00
C27 | 0.1uF |  | Skull_badge:C_0805 |  | 885012207048 | 100 | $0.00 | $0.00
C17 | 0.1uF |  | Skull_badge:C_0805 |  | 885012207045 | 100 | $0.00 | $0.00
C23 | 0.1uF |  | Skull_badge:C_0805 |  | 885012207047 | 100 | $0.00 | $0.00
C19 | 0.1uF |  | Skull_badge:C_0805 |  | 885012207046 | 100 | $0.00 | $0.00
D3 | PWR |  | Skull_badge:LED_0805 |  | 150080YS75000 | 100 | $0.00 | $0.00
U5 | LOGO |  | Skull_badge:Skull18_150x150 |  |  | 100 | $0.00 | $0.00
J6 | TopL |  | Skull_badge:Wire_Pads_1x2_4x3mm_Extended |  |  | 100 | $0.00 | $0.00
C1,C7,C12,C13 | 10uF |  | Skull_badge:C_0805 |  |  | 400 | $0.00 | $0.00
SW2 | ARD_SW |  | Skull_badge:switch_MHSS1105 |  | MHSS1105 | 100 | $0.43 | $42.80 | 18880 |  | $0.43 | $42.80 | 679-1849-ND | Link (http://www.digikey.com/product-detail/en/apem-inc/MHSS1105/679-1849-ND/1949465)
R5 | 100 |  | Skull_badge:R_0805 |  |  | 100 | $0.00 | $0.00
Y1 | 16MHz |  | Skull_badge:Q_49U3HMS |  | ABLS-16.000MHZ-B4-T | 100 | $0.00 | $0.00
J3 | TopR |  | Skull_badge:Wire_Pads_1x2_4x3mm_Extended |  |  | 100 | $0.00 | $0.00
U2 | TPS63001 |  | Housings_SON:VSON-10-1EP_3x3mm_Pitch0.5mm_ThermalPad |  | TPS63002DRCT | 100 | $0.00 | $0.00
J7 | Flight Controller Board |  | Skull_badge:Socket_Strip_Straight_2x05_Pitch2.54mm |  |  | 100 | $0.00 | $0.00
XA1 | Arduino_Uno_Shield |  | Skull_badge:UNO_headersICSP |  |  | 100 | $0.00 | $0.00
R11 | 2M |  | Skull_badge:R_0805 |  |  | 100 | $0.00 | $0.00
SW4-SW9 | SW_Push |  | Skull_badge:smd_push |  | MJTP1106STR | 600 | $0.00 | $0.00
D2 | TX |  | Skull_badge:LED_0805 |  | 150080YS75000 | 100 | $0.00 | $0.00

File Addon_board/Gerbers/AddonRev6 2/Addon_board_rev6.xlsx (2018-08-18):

Id | Designator | Package | Quantity | Designation | Supplier and ref
1 | C5 | C_0805 | 1 | C
2 | J1 | Pin_Header_Straight_1x03_Pitch2.54mm | 1 | SPI
3 | C6,C7 | C_0805 | 2 | 0.1uF
4 | D1 | LED_0805 | 1 | LED
5 | R1,R2,R5,R6 | R_0805 | 4 | 10K
6 | R3 | R_0805 | 1 | 1K
7 | R4 | R_0805 | 1 | 2K
8 | U4 | SOIC-8_3.9x4.9mm_Pitch1.27mm | 1 | 24LC256
9 | U5 | TSSOP-20_4.4x6.5mm_Pitch0.65mm | 1 | TXB0108PWR
10 | U2 | DCDC_BOOST | 1 | DD06AJSA
16 | J4 | SolderJumper | 1 | GS2 | DNS
17 | SW1,SW2,SW3 | MSK12C02 | 3 | SW_SPDT
19 | XA2 | UNO_headersICSP_EDIT_10smd | 1 | Shield
 | XA2 Parts
 |  | 1x6_Long_pin_Stackable_header Socket | 1
 |  | 1x8_Long_pin_Stackable_header Socket | 2
 |  | 1x10_SMD_header Socket | 1
 | J2 | 1x10_SMD_Long_Header_Pins | 1 | pn 87898-0657 mouser has them in stock they come in 1x6, and can be seperaded as needed

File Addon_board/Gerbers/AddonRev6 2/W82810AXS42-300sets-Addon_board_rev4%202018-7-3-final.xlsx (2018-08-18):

Id | Designator | Package | Quantity | Designation | Supplier and ref | 300sets
1 | C5 | C_0805 | 1 | C |  |  |  | offer the parameter
2 | J1 | Pin_Header_Straight_1x03_Pitch2.54mm | 1 | SPI |  | $0.022 | $0.022 | pin header 1*3pin 2.54mm
3 | C6,C7 | C_0805 | 2 | 0.1uF |  | $0.033 | $0.066
4 | D1 | LED_0805 | 1 | LED |  | $0.022 | $0.022 | LED 0805 green,made in China
5 | R1,R2,R5,R6 | R_0805 | 4 | 10K |  | $0.009 | $0.035
6 | R3 | R_0805 | 1 | 1K |  | $0.009 | $0.009
7 | R4 | R_0805 | 1 | 2K |  | $0.009 | $0.009
8 | U4 | SOIC-8_3.9x4.9mm_Pitch1.27mm | 1 | 24LC256 |  | $0.352 | $0.352 | complete part number is 24LC256T-I/SN
9 | U5 | TSSOP-20_4.4x6.5mm_Pitch0.65mm | 1 | TXB0108PWR |  | $0.792 | $0.792
10 | U2 | DCDC_BOOST | 1 | DD06AJSA |  |  |  | offer the part number or link
16 | J4 | SolderJumper | 1 | GS2 | DNS |  |  | offer the part number or link
17 | SW1,SW2,SW3 | MSK12C02 | 3 | SW_SPDT |  | $0.044 | $0.132 | MSK-12C02,made in China
19 | XA2 | UNO_headersICSP_EDIT_10smd | 1 | Shield |  |  |  | offer the part number or link
 | XA2 Parts
 |  | 1x6_Long_pin_Stackable_header Socket | 1 |  |  | $0.022 | $0.022 | pin header 1*6pin 2.54mm
 |  | 1x8_Long_pin_Stackable_header Socket | 2 |  |  | $0.022 | $0.044 | pin header 1*8pin 2.54mm
 |  | 1x10_SMD_header Socket | 1 |  |  | $0.033 | $0.033 | pin header 1*10pin 2.54mm
 | J2 | 1x10_SMD_Long_Header_Pins | 1 | pn 87898-0657 mouser has them in stock they come in 1x6, and can be seperaded as needed |  | $1.947 | $1.947 | 87898-0657 1*6pin 5-7work days
 |  |  |  |  |  | 1 set | $3.485
 |  |  |  |  |  | 300 sets | $1045.44

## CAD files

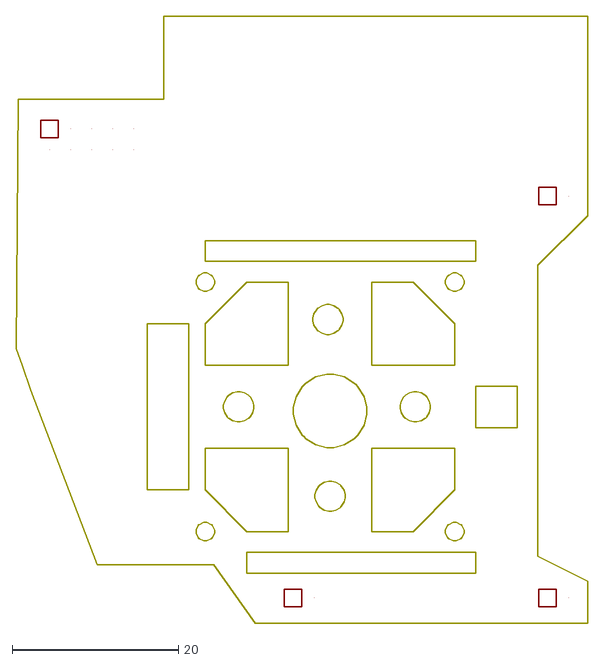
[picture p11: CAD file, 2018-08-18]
FlightControlUnitBoard V3/KiCADv5/flt_outline.dxf
68.8 x 73.0

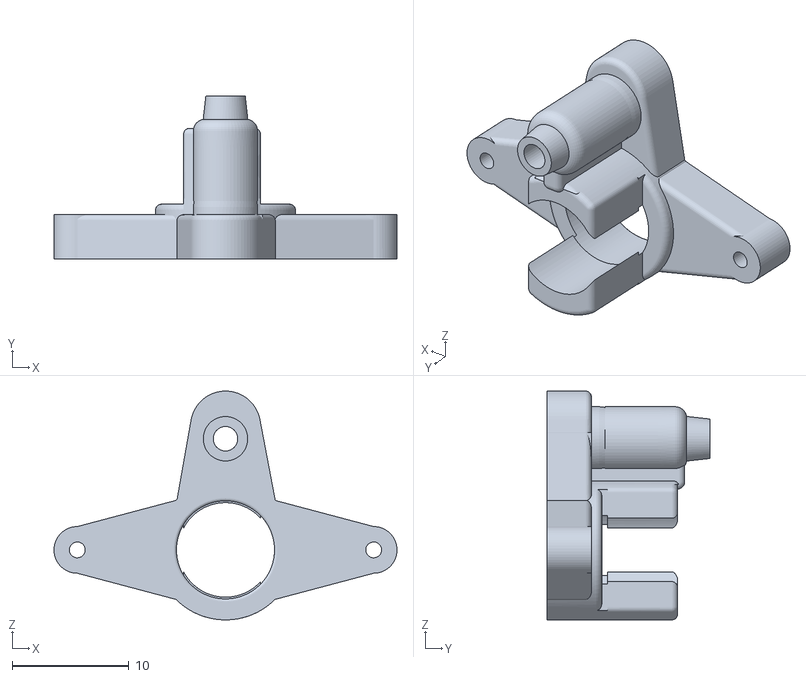
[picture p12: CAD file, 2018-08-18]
MotorMounts3D/MkVIII v19.stl
29.4 x 14.0 x 19.6

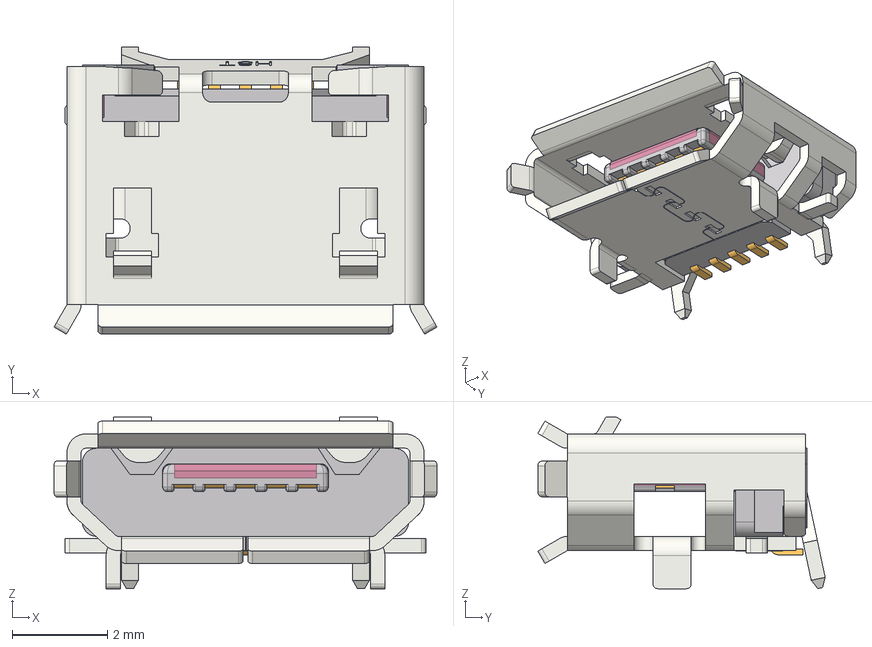
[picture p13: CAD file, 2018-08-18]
Skull_badge_V2/3D/User Library-10103594_MICRO-USB-SCOKET-HOUSING_sp.step
8.04 x 6.03 x 3.60 mm

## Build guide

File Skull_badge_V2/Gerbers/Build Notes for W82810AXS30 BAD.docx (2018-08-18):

Build Notes for W82810AXS30--S36

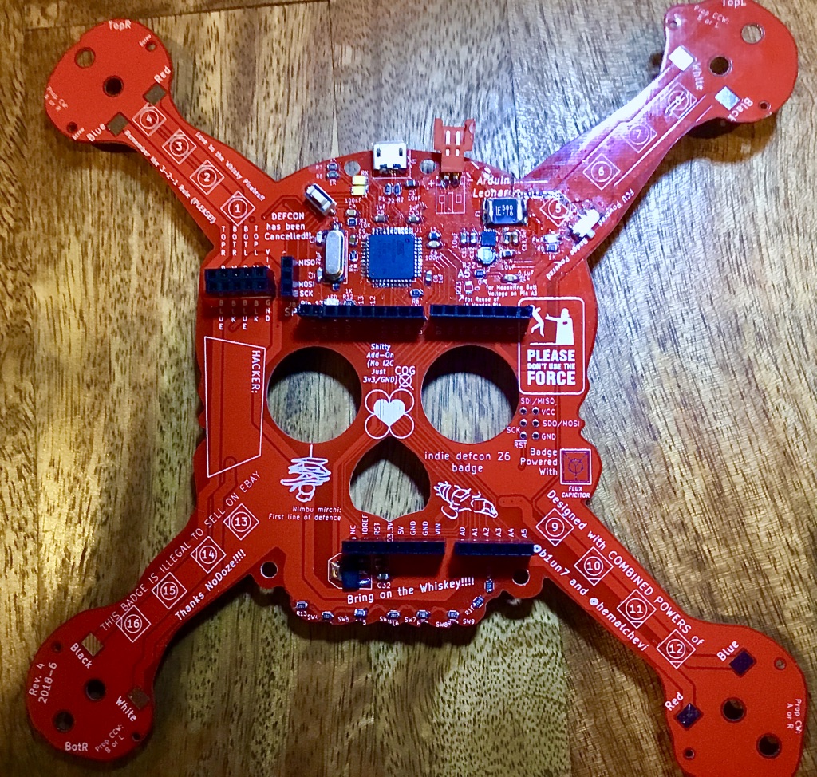
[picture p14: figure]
../../../../../Pictures/Photos%20Library.photoslibrary/resources/proxies/derivatives/02/01/10282/3GQb3ac4SCyj%25wwN20GyLA_thumb_1028
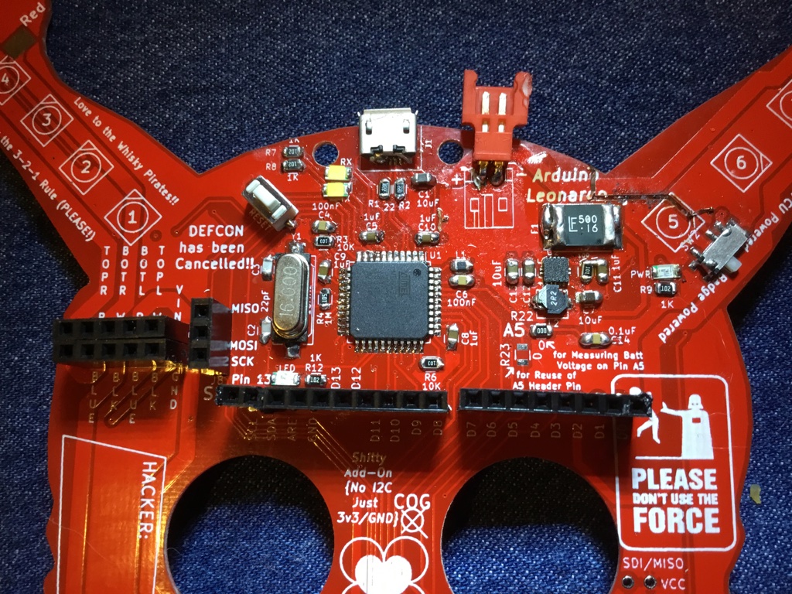
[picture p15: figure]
../../../../../Pictures/Photos%20Library.photoslibrary/resources/proxies/derivatives/02/01/10287/UNADJUSTEDNONRAW_thumb_10287.

Pin 1

Pin 1

Rev. 1 11 July 18

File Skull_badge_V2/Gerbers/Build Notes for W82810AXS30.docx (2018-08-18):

Build Notes for W82810AXS30--S36

../../../../../Pictures/Photos%20Library.photoslibrary/resources/proxies/derivatives/02/01/10282/3GQb3ac4SCyj%25wwN20GyLA_thumb_1028
../../../../../Pictures/Photos%20Library.photoslibrary/resources/proxies/derivatives/02/01/10287/UNADJUSTEDNONRAW_thumb_10287.

Pin 1

Pin 1

Rev. 1 11 July 18

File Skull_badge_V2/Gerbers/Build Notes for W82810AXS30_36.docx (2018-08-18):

Build Notes for W82810AXS30--S36

../../../../../Pictures/Photos%20Library.photoslibrary/resources/proxies/derivatives/02/01/10282/3GQb3ac4SCyj%25wwN20GyLA_thumb_1028

IC’s

Pin 1

Pin 1

LEDs

Do Not Source or Populate

Capacitors

10 uF

10 uF

1 uF

100 nF

1 uF

1 uF

1 uF

22 pf

22 pF

100 nF

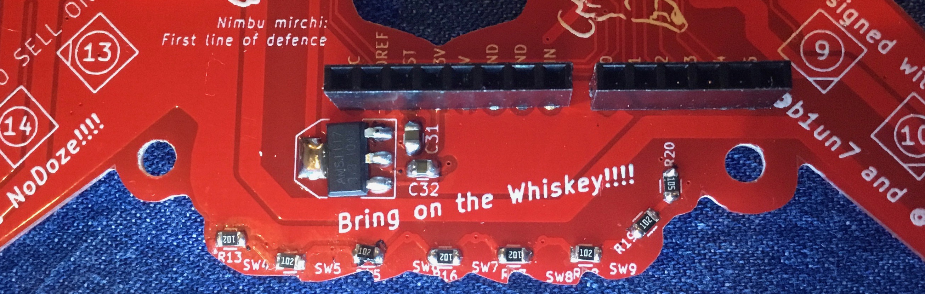
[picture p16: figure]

10 uF

10 uF

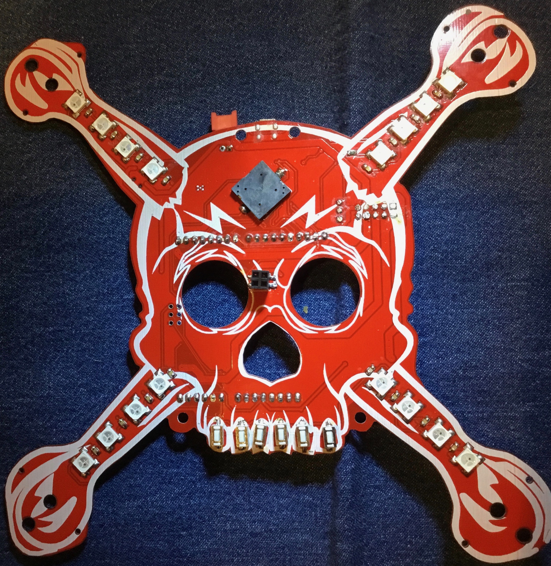
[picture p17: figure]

100 nF

100 nF

100 nF

100 nF

100 nF

100 nF

100 nF

100 nF

100 nF

100 nF

100 nF

100 nF

100 nF

100 nF

100 nF

100 nF

Resisters

1 M

10K

1K

1K

100 R

0 R

10K

1 uF

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
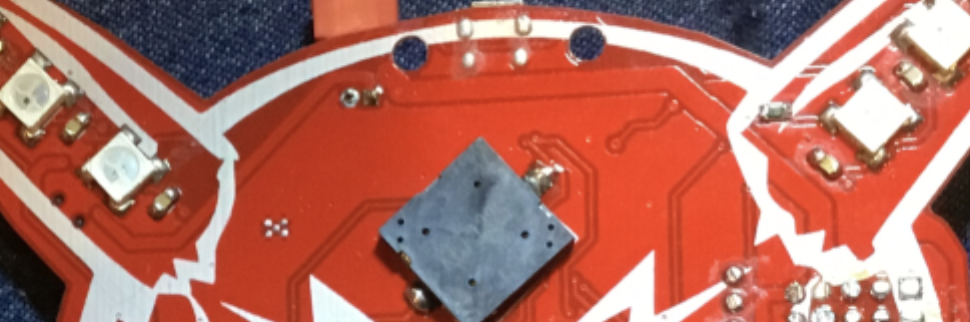
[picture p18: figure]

300 R

Rev. 1 Rev. 1 11 July 18

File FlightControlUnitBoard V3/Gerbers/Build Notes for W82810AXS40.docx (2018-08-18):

Build Notes for W82810AXS40

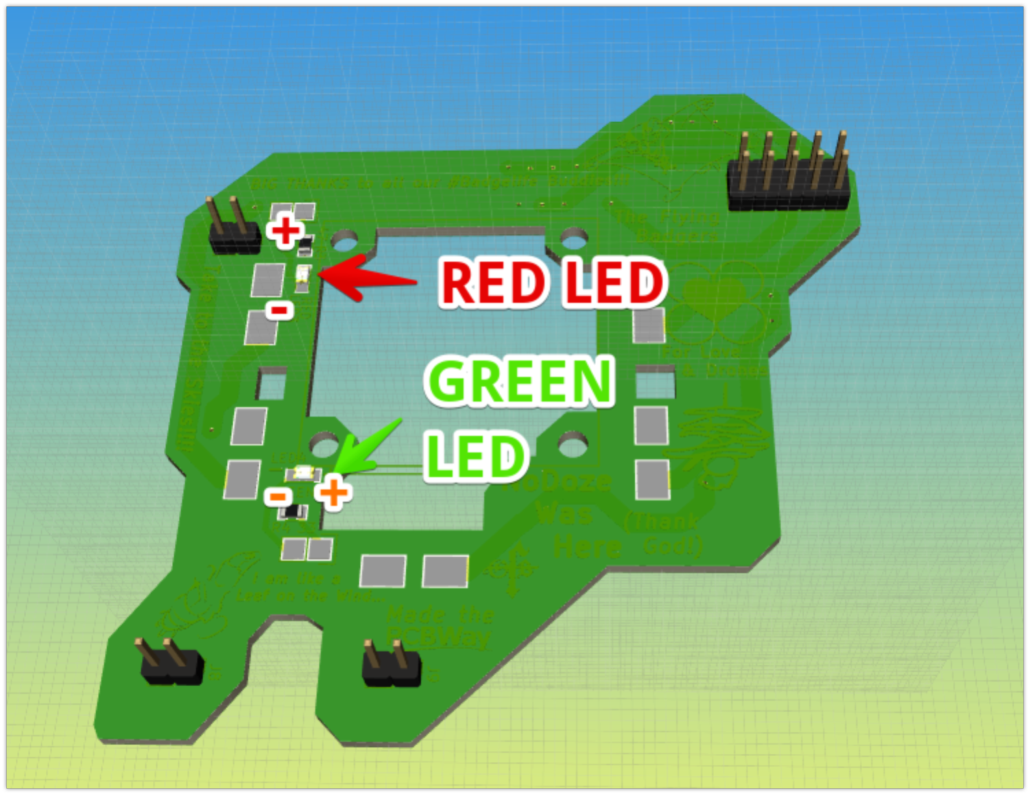
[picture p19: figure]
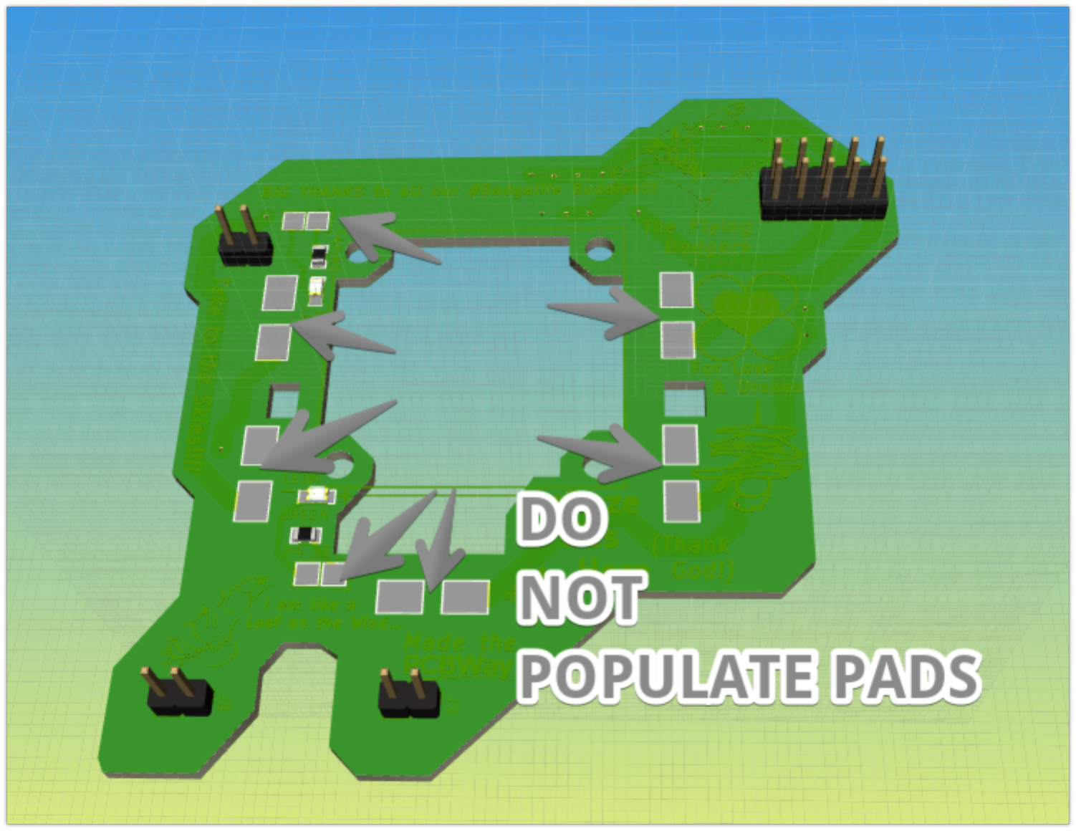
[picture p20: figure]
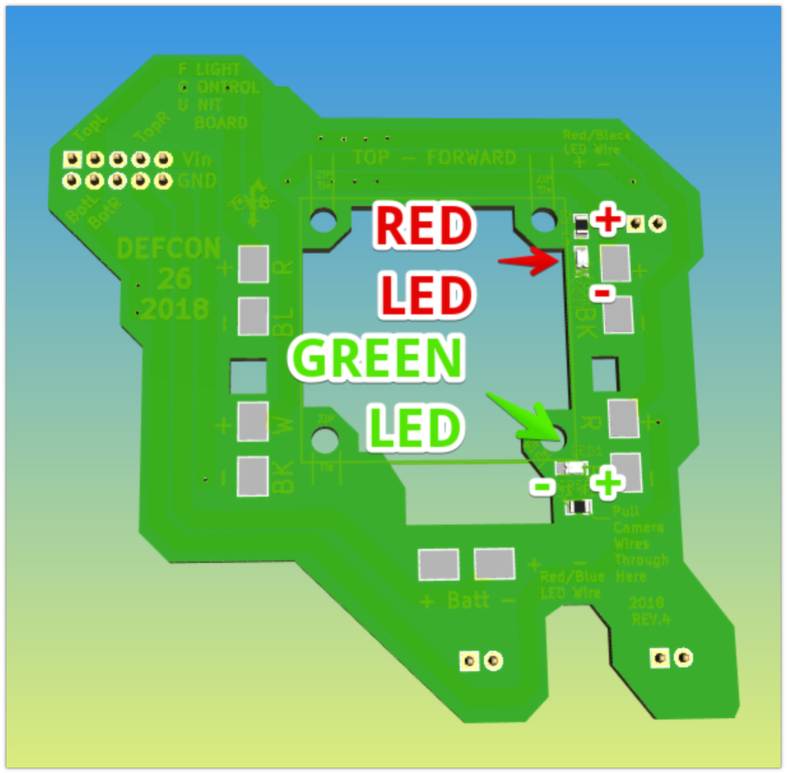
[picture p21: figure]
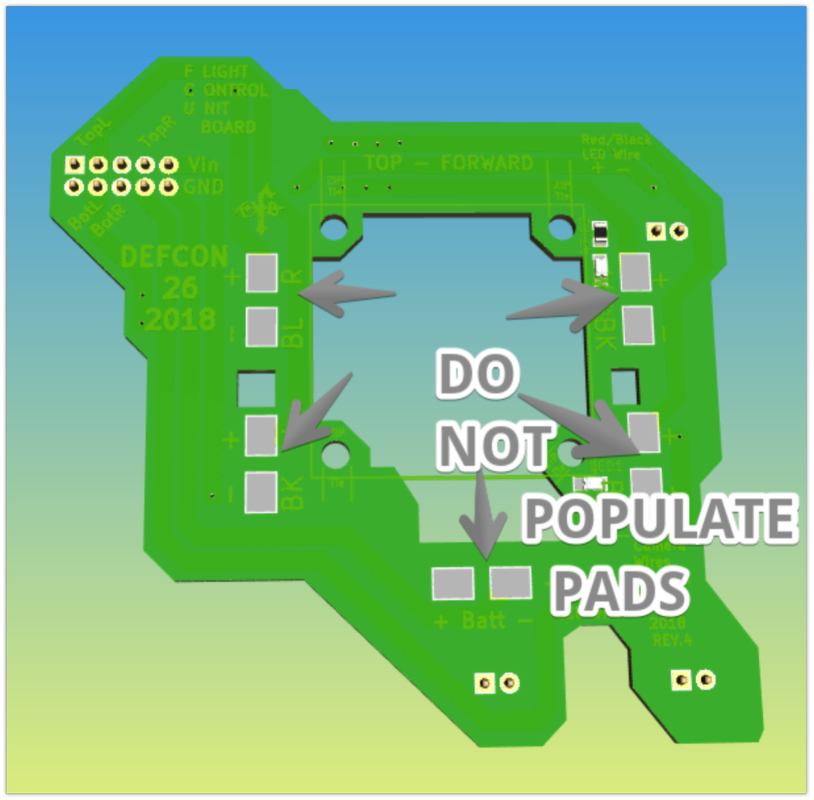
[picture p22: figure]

Rev. 1 16 July 18

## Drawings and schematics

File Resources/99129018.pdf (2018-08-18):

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

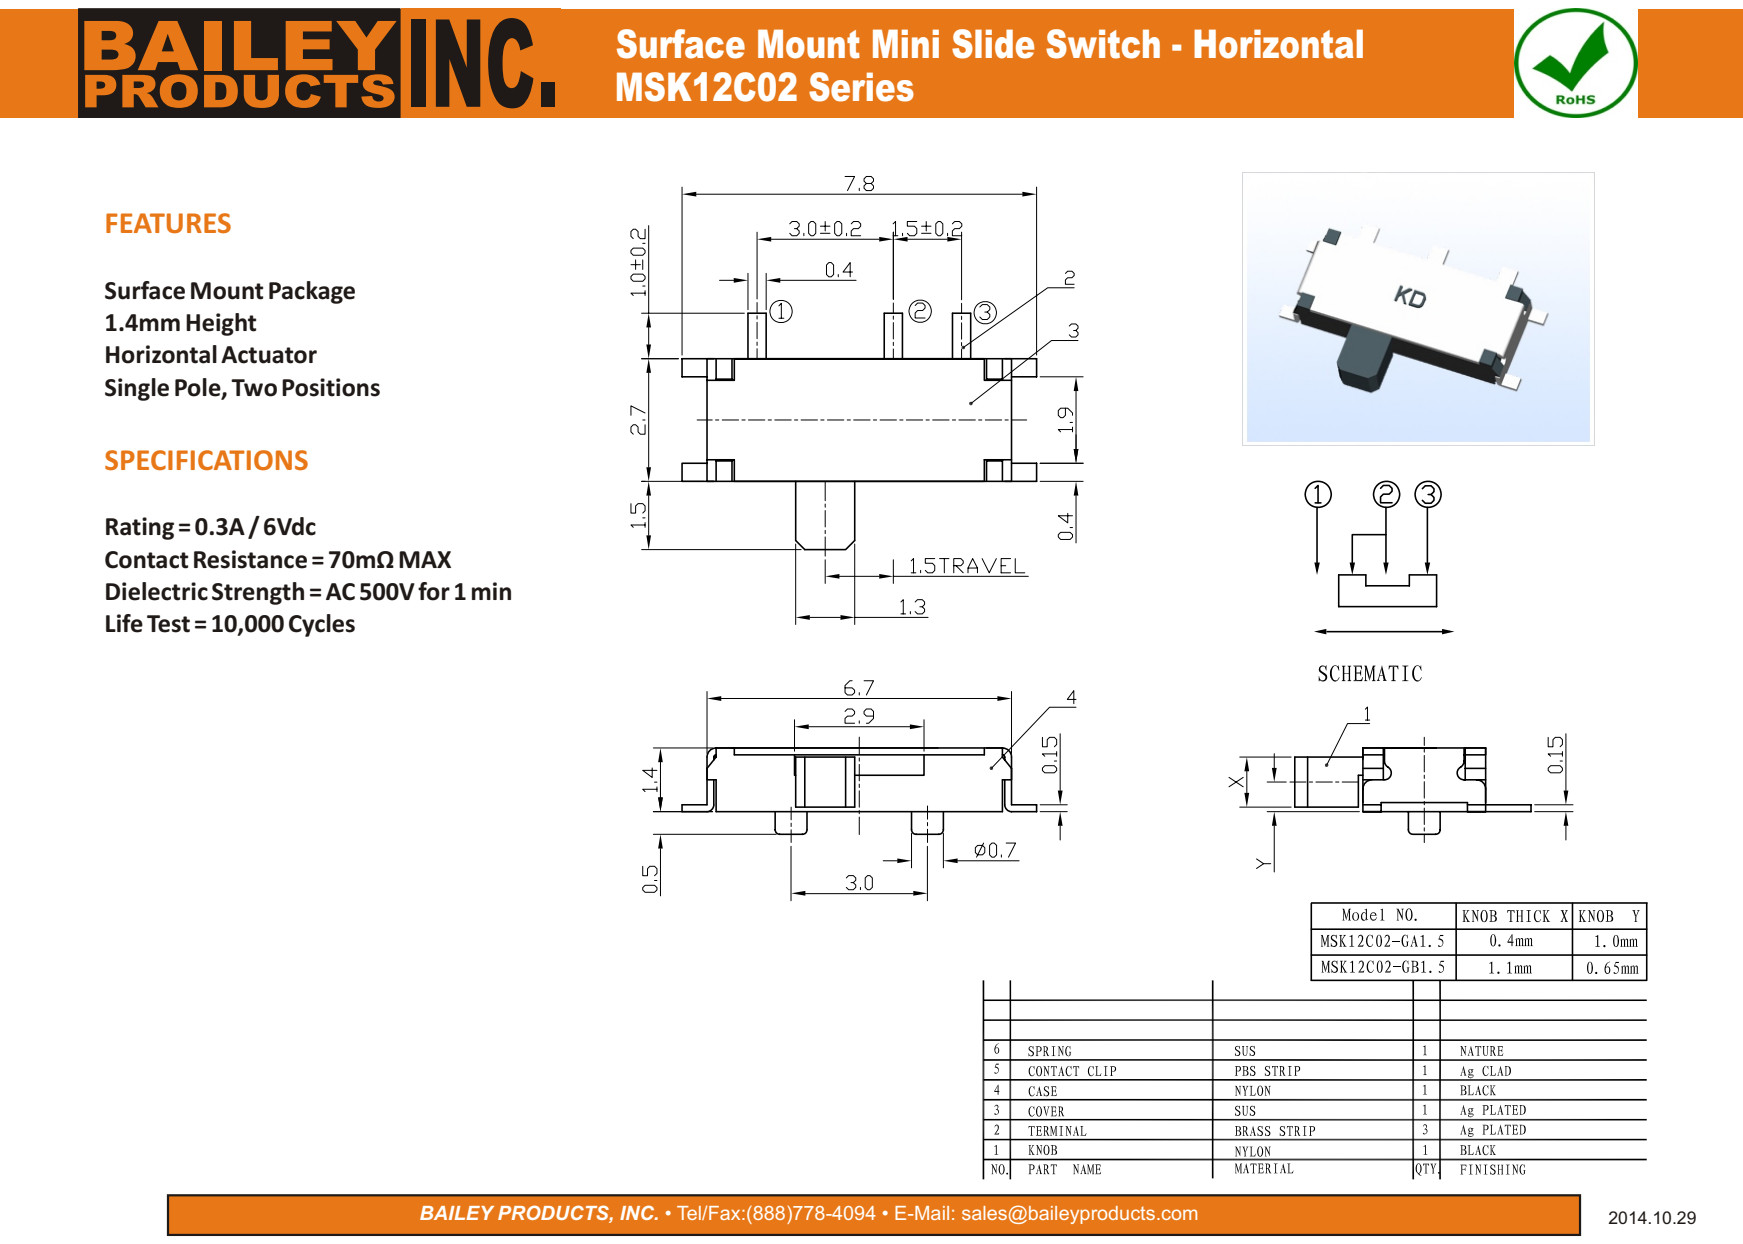
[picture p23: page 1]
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

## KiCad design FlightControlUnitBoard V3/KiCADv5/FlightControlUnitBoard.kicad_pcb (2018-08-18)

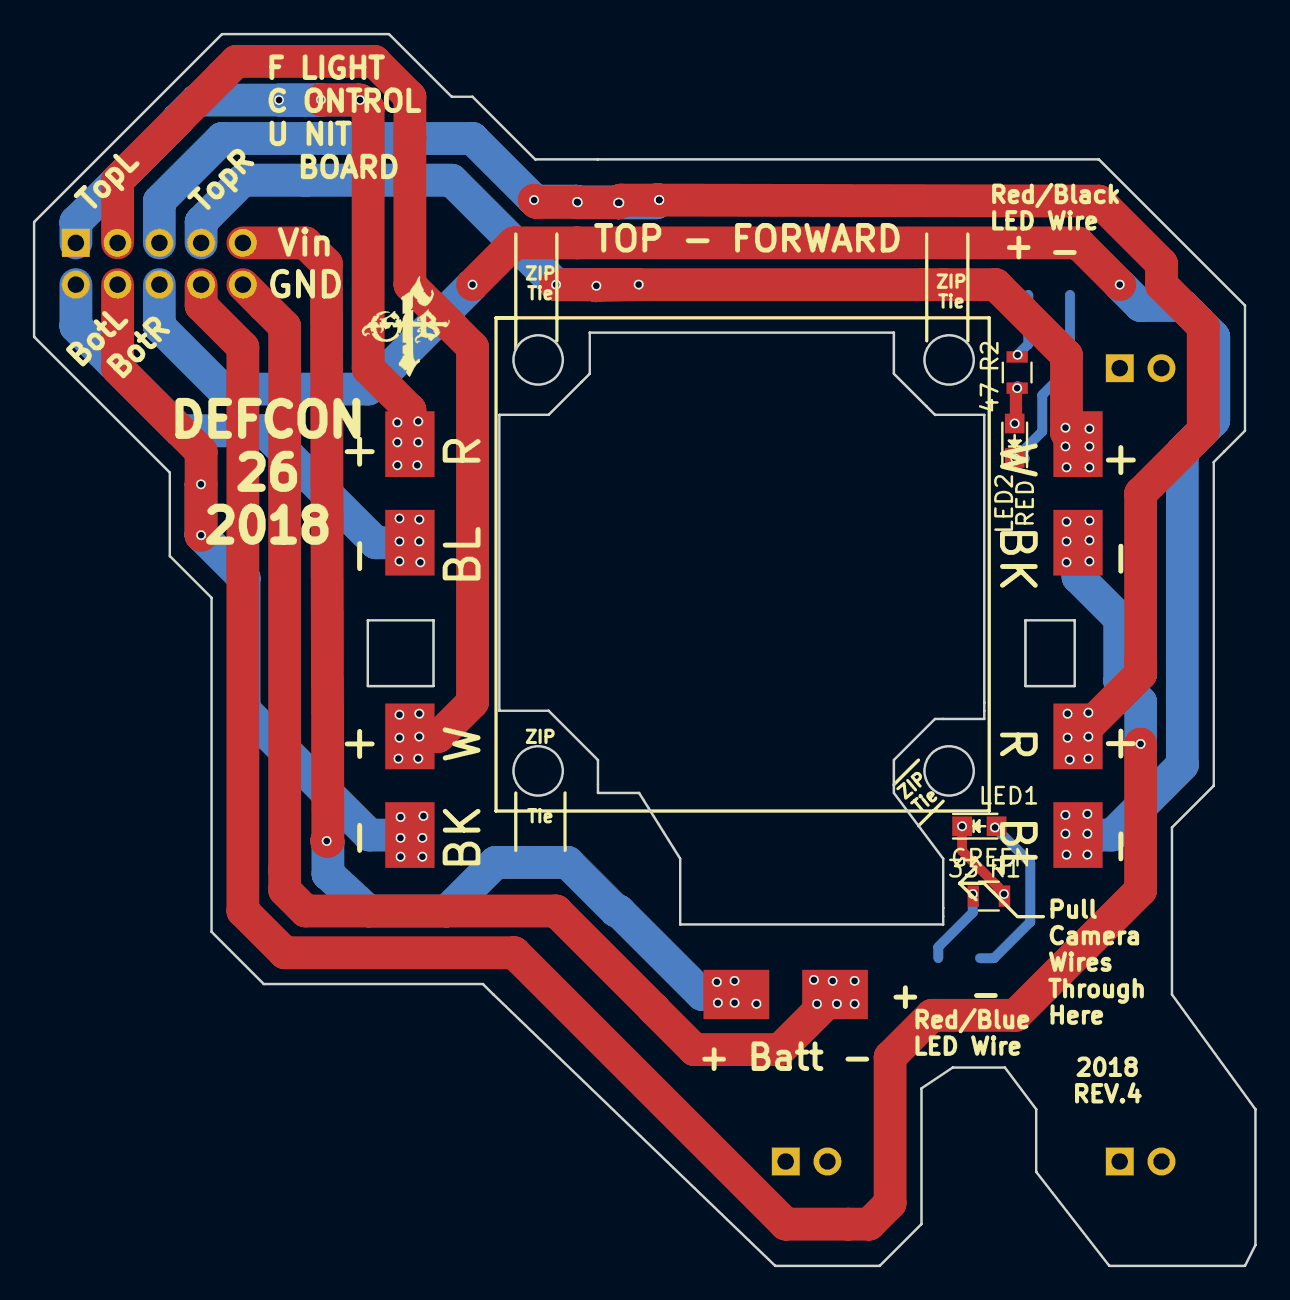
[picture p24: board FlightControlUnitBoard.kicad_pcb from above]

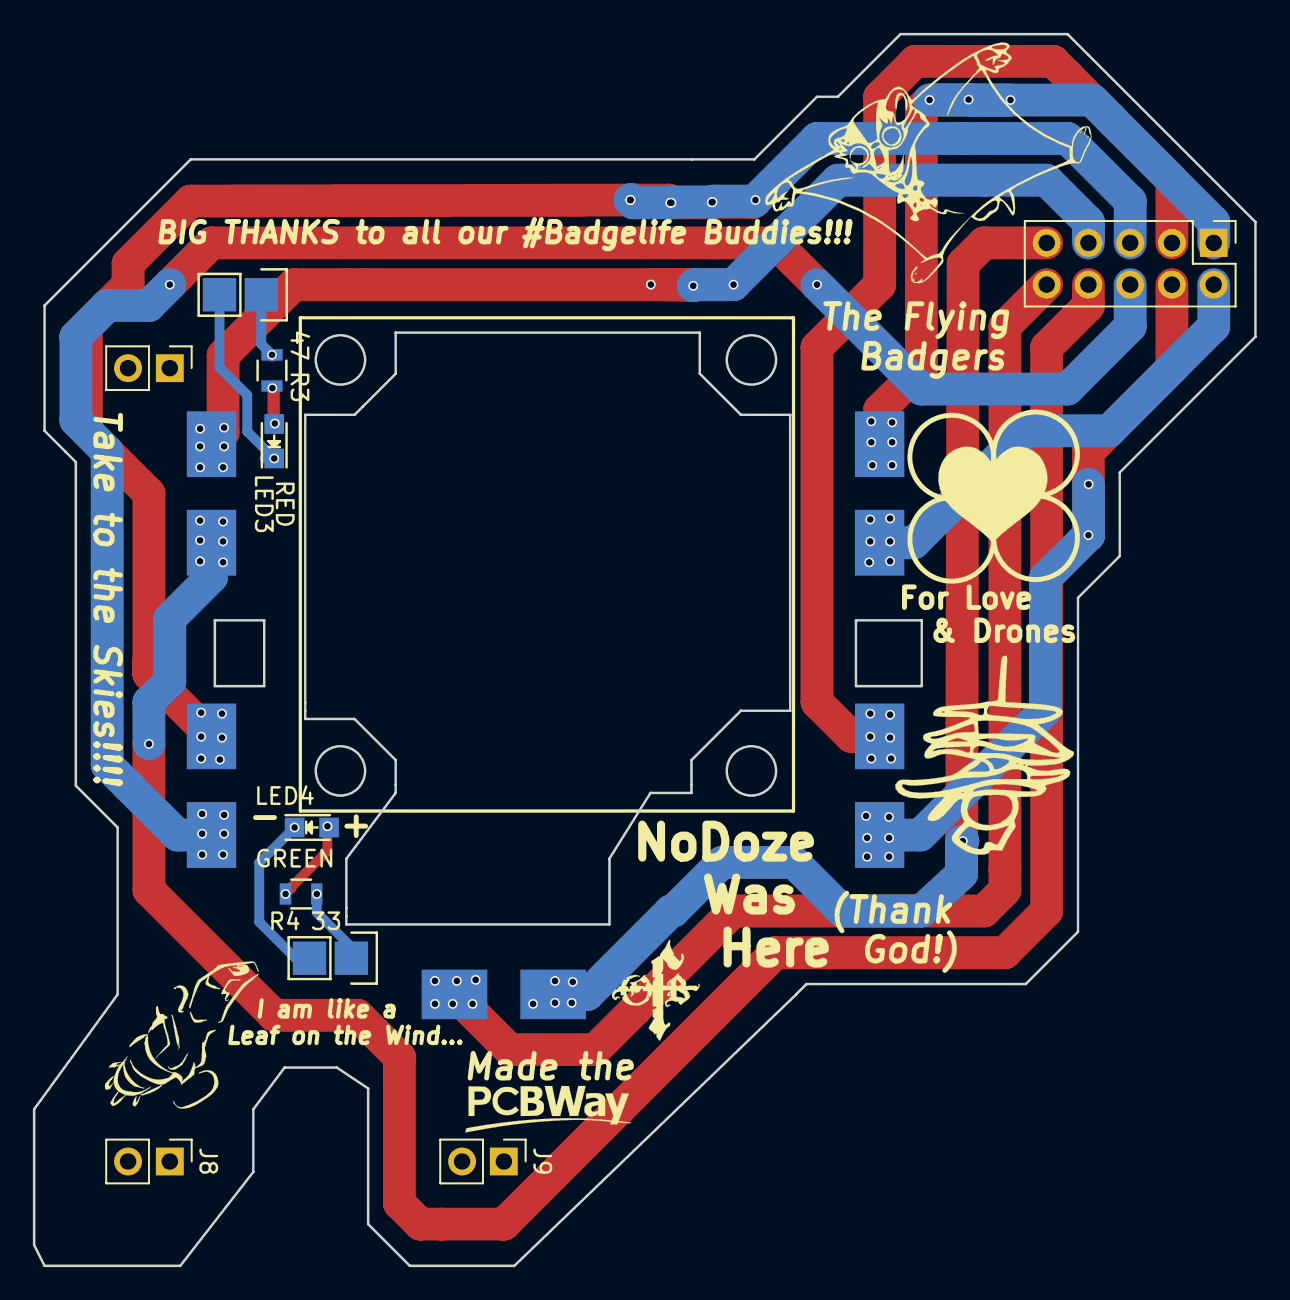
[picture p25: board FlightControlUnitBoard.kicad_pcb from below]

Board: 2 copper layers, 74.3 x 74.9 mm, 24 parts (15 on the bottom side), 10 nets.

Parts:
J1: Conn_02x05_Odd_Even; Pin_Header_Straight_2x05_Pitch2.54mm
J2, J2#2, J3, J3#2, J4, J4#2, J5, J5#2, J6, J6#2: Conn_01x02_Male; Wire_Pads_1x2_4x3mm
J7, J8, J9: Conn_02x01; Pin_Header_Straight_1x02_Pitch2.54mm
J10, J11: Pin_Header_Straight_1x02
LED1, LED4: GREEN; LED_0805
LED2, LED3: RED; LED_0805
R1, R4: 33; R_0805
R2, R3: 47; R_0805

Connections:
unnamed: J1.1, J3.1, J3#2.1
unnamed: J1.2, J3.2, J3#2.2
unnamed: J1.3, J4.1, J4#2.1
unnamed: J1.4, J4.2, J4#2.2
unnamed: J1.5, J6.1, J6#2.1
unnamed: J1.6, J6.2, J6#2.2
unnamed: J1.7, J5.1, J5#2.1
unnamed: J1.8, J5.2, J5#2.2
unnamed: J1.9, J2.2, J2#2.2, J9.2
unnamed: J1.10, J2.1, J2#2.1, J9.1

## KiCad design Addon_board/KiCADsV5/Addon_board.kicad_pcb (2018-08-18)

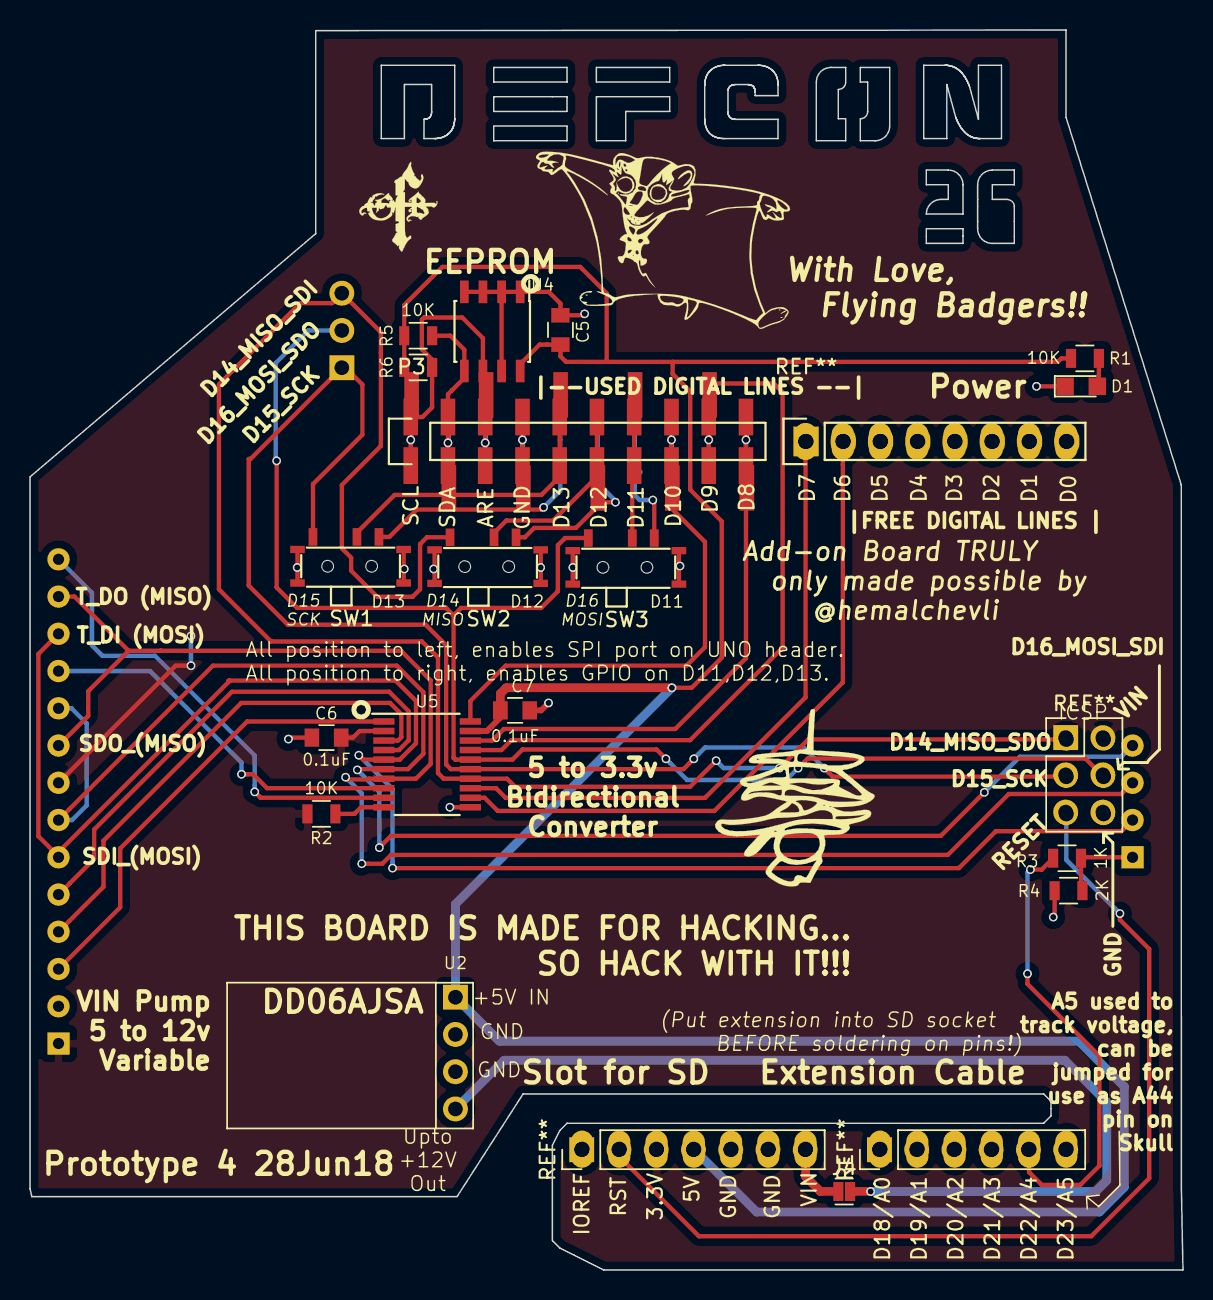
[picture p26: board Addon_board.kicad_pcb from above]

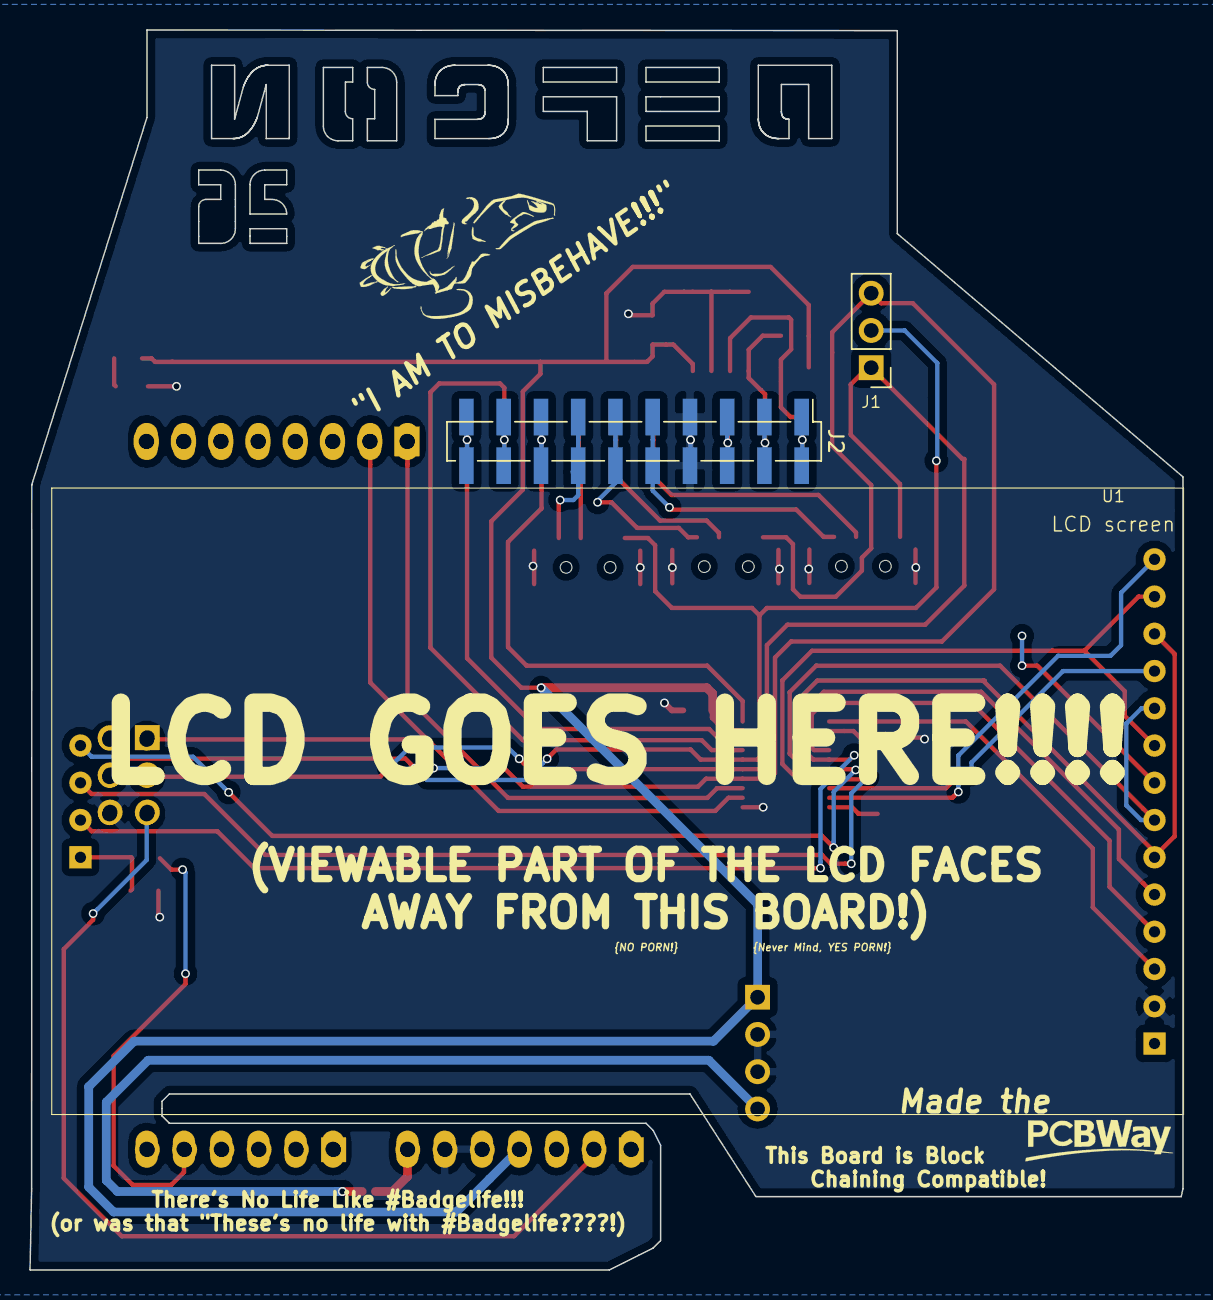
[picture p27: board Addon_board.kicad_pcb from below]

Board: 2 copper layers, 78.6 x 84.5 mm, 22 parts (3 on the bottom side), 35 nets.

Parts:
C5: 10 pF; C_0805
C6, C7: 0.1uF; C_0805
D1: LED; LED_0805
J1: SPI; Pin_Header_Straight_1x03_Pitch2.54mm
J2: BottomConn; Pin_Header_Straight_1x10_Pitch2.54mm_SMD_Pin1Left
J4: GS2; SolderJumper
P3: Digital Header 02; Socket_Strip_Straight_1x10_2.54_SMD
R1, R2, R5, R6: 10K; R_0805
R3: 1K; R_0805
R4: 2K; R_0805
SW1, SW2, SW3: SW_SPDT; MSK12C02
U1: 2.4TFT_LCD; 2.4_TFT_LCD_OUTLINE
U2: DD06AJSA; DCDC_BOOST
U4: 24LC256; SOIC-8_3.9x4.9mm_Pitch1.27mm
U5: TXB0108PWR; TSSOP-20_4.4x6.5mm_Pitch0.65mm
XA2: Shield; UNO_headersICSP_EDIT_10smd

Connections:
/+3V3: C6.1, R2.2, U1.1, U1.8, U5.2, XA2.3V3, XA2.SP2
/+5V: C5.1, C7.1, R1.1, R5.2, R6.2, U2.1, U4.8, U5.19, XA2.5V
/+12V: J4.2, U2.4
/A4: R3.1, XA2.A4
/A4_3V3: R3.2, R4.1, U1.15
/AREF: J2.3, XA2.AREF
/D6: U5.12, XA2.D6
/D6_3V3: U1.14, U5.9
/D7: U5.13, XA2.D7
/D7_3V3: U1.11, U5.8
/D8: J2.10, U5.18, XA2.D8
/D8_3V3: U1.4, U5.3
/D9: J2.9, U5.17, XA2.D9
/D9_3V3: U1.5, U5.4
/D10: J2.8, U5.20, XA2.D10
/D10_3V3: U1.3, U5.1
/D11: J2.7, SW3.3
/D12: J2.6, SW2.3
/D13: J2.5, SW1.3
/DD11: SW3.2, XA2.D11
/DD12: SW2.2, XA2.D12
/DD13: SW1.2, XA2.D13
/MISO_3V3: U1.9, U1.13, U1.17, U5.7
/MISO_5V: J1.3, SW2.1, U5.14, XA2.SP1
/MOSI_3V3: U1.6, U1.12, U1.16, U5.5
/MOSI_5V: J1.2, SW3.1, U5.16, XA2.SP4
/SCL: J2.1, R6.1, U4.6, XA2.SCL
/SCLK_3V3: U1.7, U1.10, U1.18, U5.6
/SCLK_5V: J1.1, SW1.1, U5.15, XA2.SP3
/SDA: J2.2, R5.1, U4.5, XA2.SDA
GND: C5.2, C6.2, C7.2, D1.1, J2.4, R4.2, SW1.4, SW2.4, SW3.4, U1.2, U2.2, U2.3, U4.1, U4.2, U4.3, U4.4, U4.7, U5.11, XA2.GND1, XA2.GND2, XA2.GND3, XA2.SP6
unnamed: D1.2, R1.2
unnamed: J4.1, XA2.VIN
unnamed: R2.1, U5.10
unnamed: XA2.RST, XA2.SP5

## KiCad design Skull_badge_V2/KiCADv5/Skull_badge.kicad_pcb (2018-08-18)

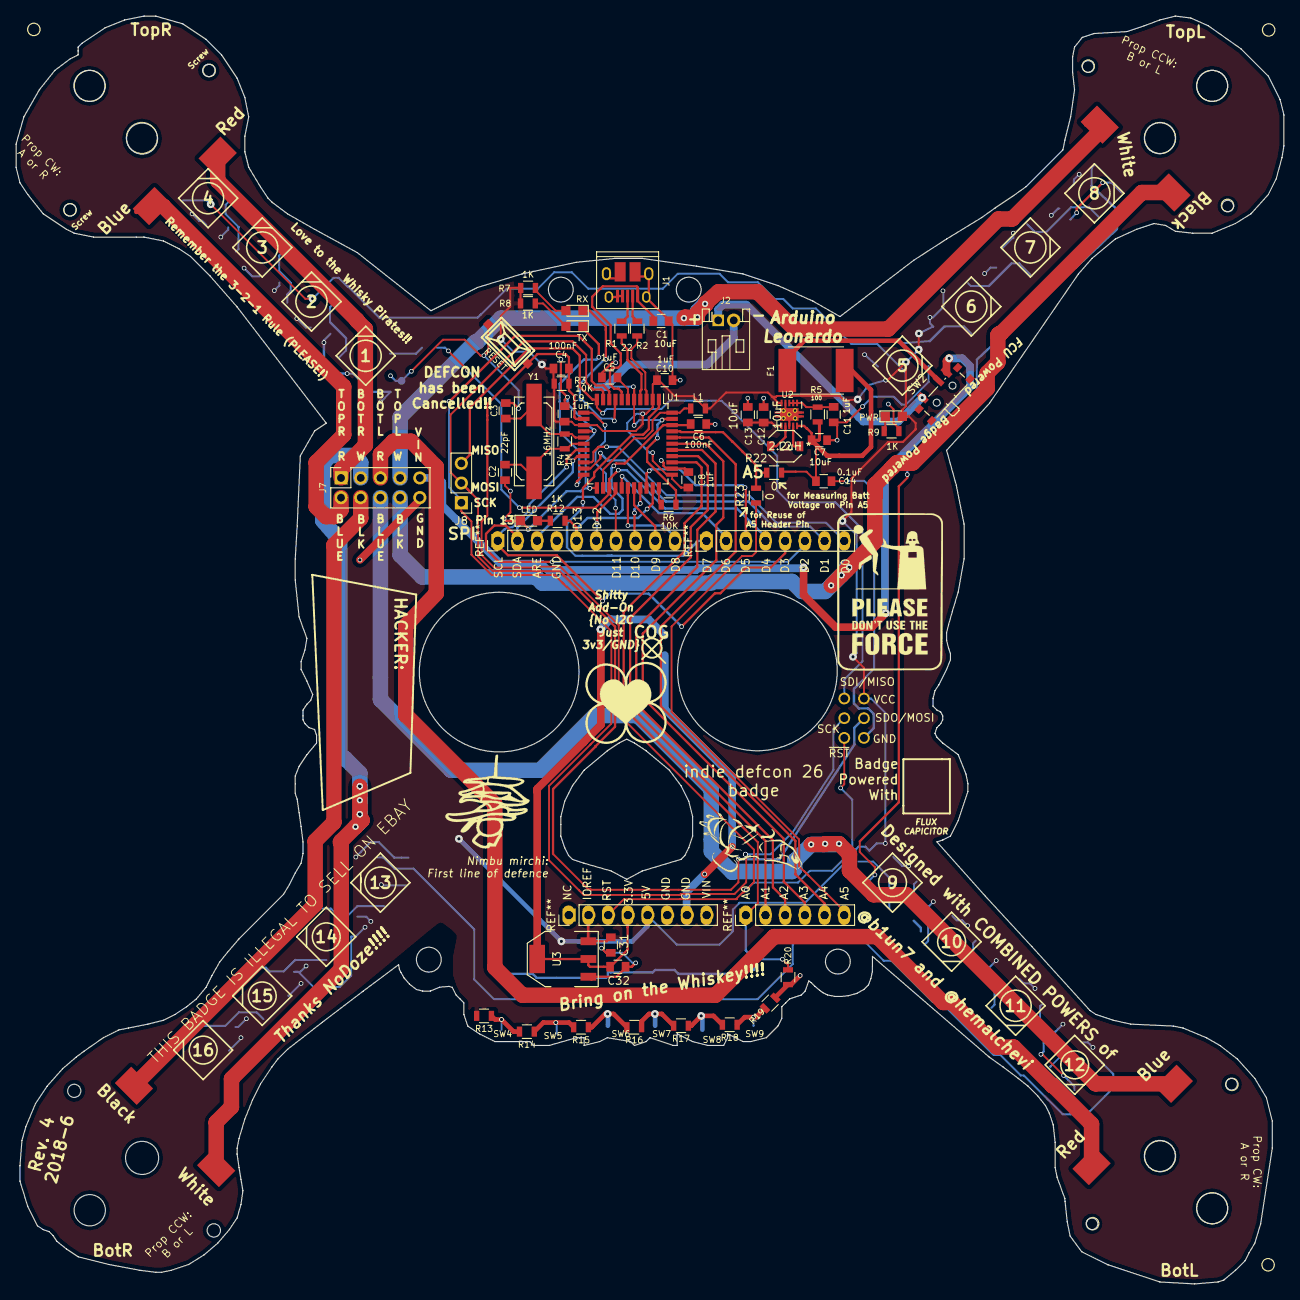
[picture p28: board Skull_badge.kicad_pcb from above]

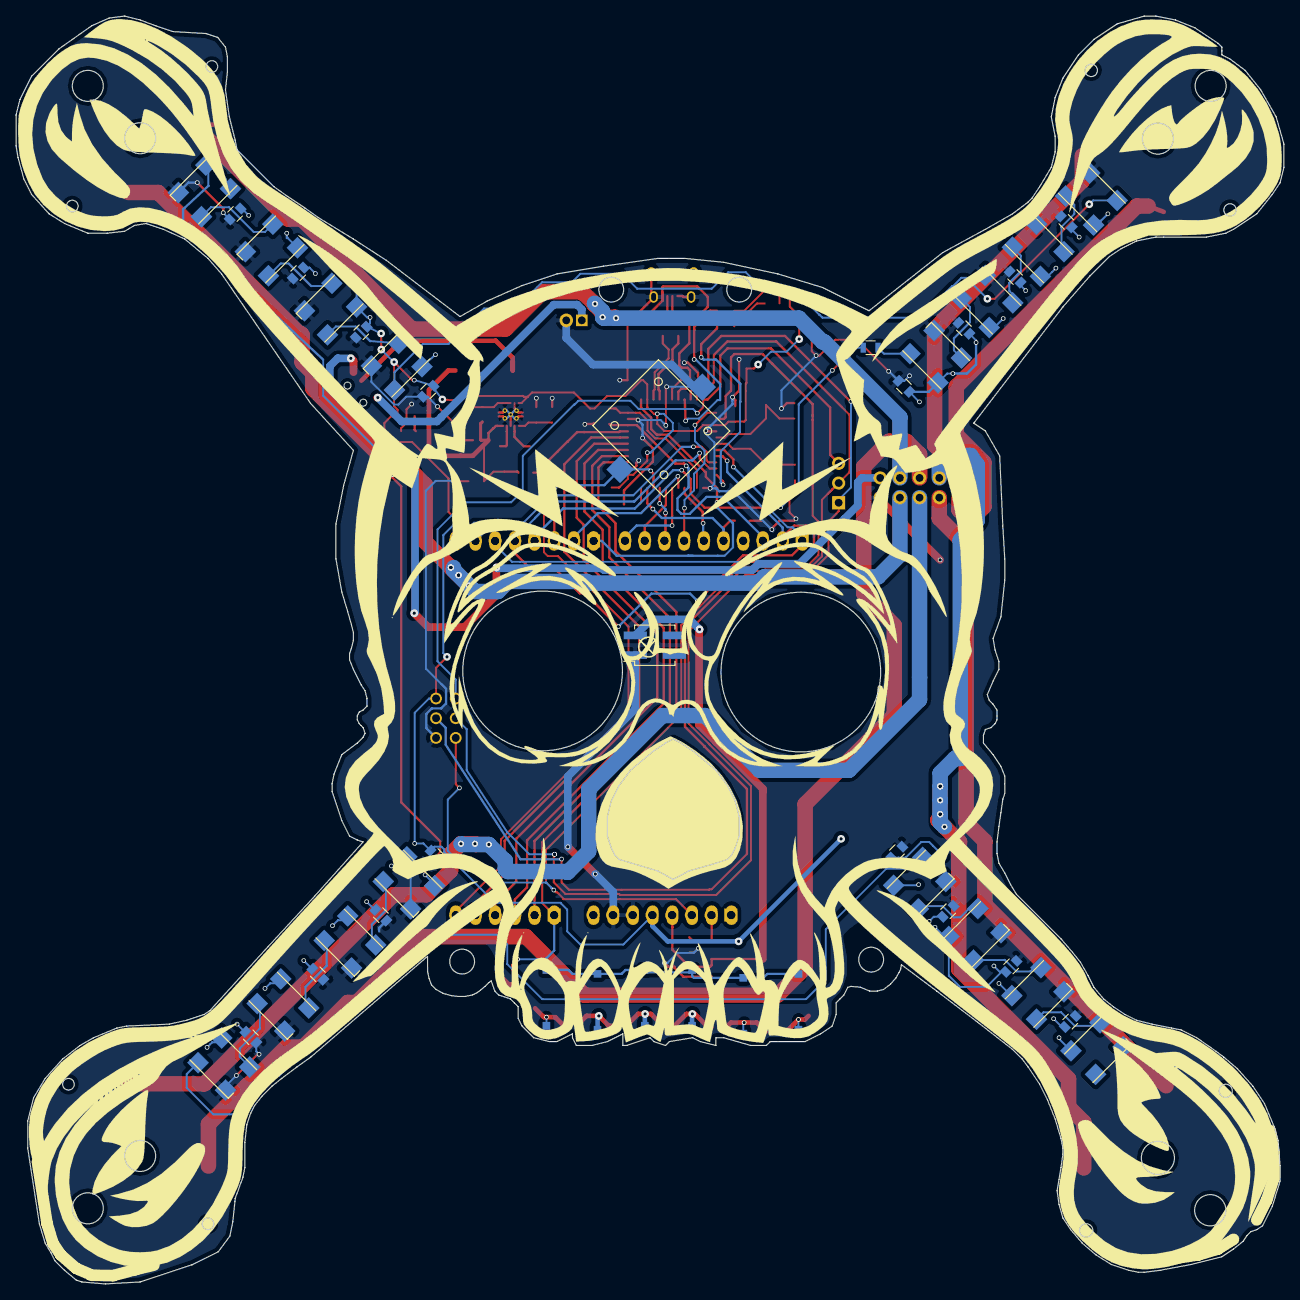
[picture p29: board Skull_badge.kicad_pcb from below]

Board: 2 copper layers, 163.5 x 163.5 mm, 101 parts (42 on the bottom side), 79 nets.

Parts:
C1, C7, C12, C13, C31, C32: 10uF; C_0805
C2, C3: 22pF; C_0805
C4, C6: 100nF; C_0805
C5, C8, C9, C10, C11: 1uF; C_0805
C14, C15, C16, C17, C18, C19, C20, C21, C22, C23, C24, C25, C26, C27, C28, C29, C30: 0.1uF; C_0805
D1: RX; LED_0805
D2: TX; LED_0805
D3: PWR; LED_0805
D4: LED; LED_0805
F1: Fuse; Fuse_SMD2920
J1: USB_OTG; USB_Micro-B_10103594-0001LF
J2: LiPo; JST_PH_S2B-PH-K_02x2.00mm_Angled
J3: TopR; Wire_Pads_1x2_4x3mm_Extended
J4: BtmL; Wire_Pads_1x2_4x3mm_Extended
J5: BtmR; Wire_Pads_1x2_4x3mm_Extended
J6: TopL; Wire_Pads_1x2_4x3mm_Extended
J7: Flight Controller Board; Socket_Strip_Straight_2x05_Pitch2.54mm
J8: SPI; Pin_Header_Straight_1x03_Pitch2.54mm
L1: L; L_0805
L2: 2.2uH; VLF4012AT-2R2M1R5
LS1: Speaker_Crystal; piezo_KJL_1325
R1, R2: 22; R_0805
R3, R6: 10K; R_0805
R4, R20: 1M; R_0805
R5: 100; R_0805
R7, R8, R9, R12, R13, R14, R15, R16, R17, R18, R19: 1K; R_0805
R21: 300; R_0805
R22, R23: 0; R_0805
SW1: RESET; smd_push
SW2: ARD_SW; SW_SPDT_PCM12
SW4, SW5, SW6, SW7, SW8, SW9: SW_Push; smd_push
U1: ATMEGA32U4-AU; TQFP-44_10x10mm_Pitch0.8mm
U2: TPS63002; VSON-10-1EP_3x3mm_Pitch0.5mm_ThermalPad
U3: AZ1117-3.3; SOT-223_edit
U5: LOGO; Skull18_150x150
U6: Lime_pepper; lime_pepper
U9, U10, U11, U12, U13, U14, U15, U16, U17, U18, U19, U20, U21, U22, U23, U24: WS2812B; LED_WS2812B-PLCC4_LG_PADS
X1: Badgelife_shitty_connector; Socket_Strip_Straight_2x02_Pitch2.54mm_SMD
XA1: Arduino_Uno_Shield; UNO_headersICSP
Y1: 16MHz; Q_49U3HMS

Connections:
+5V: C4.1, C8.1, C9.1, C10.1, C12.1, C13.1, C15.1, C16.1, C17.1, C18.1, C19.1, C20.1, C21.1, C22.1, C23.1, C24.1, C25.1, C26.1, C27.1, C28.1, C29.1, C30.1, C31.1, D3.2, L1.1, R3.1, R7.2, R8.2, R13.2, U1.2, U1.14, U1.34, U2.1, U2.10, U3.3, U9.1, U10.1, U11.1, U12.1, U13.1, U14.1, U15.1, U16.1, U17.1, U18.1, U19.1, U20.1, U21.1, U22.1, U23.1, U24.1, XA1.5V, XA1.IO, XA1.SP2
/+3V3: C32.1, U3.2, X1.1, XA1.3V3
/+4.2V: J2.1, SW2.1
/+4.2V_ARD: C7.1, C14.1, F1.1, F1.2, R5.2, R22.2, R23.1, SW2.2, U2.5, XA1.A5
/+4.2V_FLT: J7.9, R22.1, R23.2, SW2.3, U1.41
/A1: U1.37, XA1.A1
/A2: U1.38, XA1.A2
/A3: U1.39, XA1.A3
/AREF: C6.1, U1.42, XA1.AREF
/BL1: J4.1, J7.6
/BL2: J4.2, J7.5
/BR1: J5.1, J7.4
/BR2: J5.2, J7.3
/Button_ADC: R20.2, SW4.2, SW5.2, SW6.2, SW7.2, SW8.2, SW9.2, U1.36, XA1.A0
/D0: U1.20, XA1.D0
/D1: U1.21, XA1.D1
/D2_SDA: U1.19, XA1.D2, XA1.SDA
/D3_SCL: U1.18, XA1.D3, XA1.SCL
/D11: U1.12, XA1.D11
/D12: U1.26, XA1.D12
/D13: R12.2, U1.32, XA1.D13
/D+: R1.1, U1.4
/D-: R2.1, U1.3
/LCD_CS: U1.30, XA1.D10
/LCD_DC: U1.29, XA1.D9
/LCD_RESET: U1.28, XA1.D8
/MISO: J8.3, U1.11, XA1.SP1
/MOSI: J8.2, U1.10, XA1.SP4
/Piezo: LS1.1, U1.31, XA1.D5
/RGB_DATA: R21.2, U1.25, XA1.D4
/SCK: J8.1, U1.9, XA1.SP3
/SD_CS: U1.40, XA1.A4
/TL1: J6.1, J7.8
/TL2: J6.2, J7.7
/TOUCH_CS: U1.1, XA1.D7
/TOUCH_IRQ: U1.27, XA1.D6
/TR1: J3.1, J7.2
/TR2: J3.2, J7.1
/VBUS: C1.1, J1.1, U1.7
/xD+: J1.3, R1.2
/xD-: J1.2, R2.2
/~RESET: C4.2, R3.2, SW1.2, U1.13, XA1.RST, XA1.SP5
GND: C1.2, C2.2, C3.2, C5.2, C6.2, C7.2, C8.2, C9.2, C10.2, C11.2, C12.2, C13.2, C14.2, C15.2, C16.2, C17.2, C18.2, C19.2, C20.2, C21.2, C22.2, C23.2, C24.2, C25.2, C26.2, C27.2, C28.2, C29.2, C30.2, C31.2, C32.2, D4.1, J1.4, J1.5, J1.6, J2.2, J7.10, LS1.2, R6.1, R9.1, R19.1, R20.1, SW1.1, U1.5, U1.15, U1.23, U1.35, U1.43, U2.3, U2.9, U2.11, U3.1, U9.3, U10.3, U11.3, U12.3, U13.3, U14.3, U15.3, U16.3, U17.3, U18.3, U19.3, U20.3, U21.3, U22.3, U23.3, U24.3, X1.2, XA1.GND1, XA1.GND2, XA1.SP6
unnamed: C2.1, R4.1, U1.17, Y1.1
unnamed: C3.1, R4.2, U1.16, Y1.2
unnamed: C5.1, U1.6
unnamed: C11.1, R5.1, U2.6, U2.7, U2.8
unnamed: D1.1, U1.8
unnamed: D1.2, R7.1
unnamed: D2.1, U1.22
unnamed: D2.2, R8.1
unnamed: D3.1, R9.2
unnamed: D4.2, R12.1
unnamed: L1.2, U1.24, U1.44
unnamed: L2.1, U2.4
unnamed: L2.2, U2.2
unnamed: R6.2, U1.33
unnamed: R13.1, R14.2, SW4.1
unnamed: R14.1, R15.2, SW5.1
unnamed: R15.1, R16.2, SW6.1
unnamed: R16.1, R17.2, SW7.1
unnamed: R17.1, R18.2, SW8.1
unnamed: R18.1, R19.2, SW9.1
unnamed: R21.1, U11.4
unnamed: U10.2, U14.4
unnamed: U10.4, U24.2
unnamed: U11.2, U15.4
unnamed: U12.2, U16.4
unnamed: U12.4, U23.2
unnamed: U13.2, U17.4
unnamed: U9.2, U13.4
unnamed: U14.2, U18.4
unnamed: U15.2, U19.4
unnamed: U16.2, U20.4
unnamed: U17.2, U21.4
unnamed: U18.2, U22.4
unnamed: U19.2, U23.4
unnamed: U20.2, U24.4
unnamed: U9.4, U22.2

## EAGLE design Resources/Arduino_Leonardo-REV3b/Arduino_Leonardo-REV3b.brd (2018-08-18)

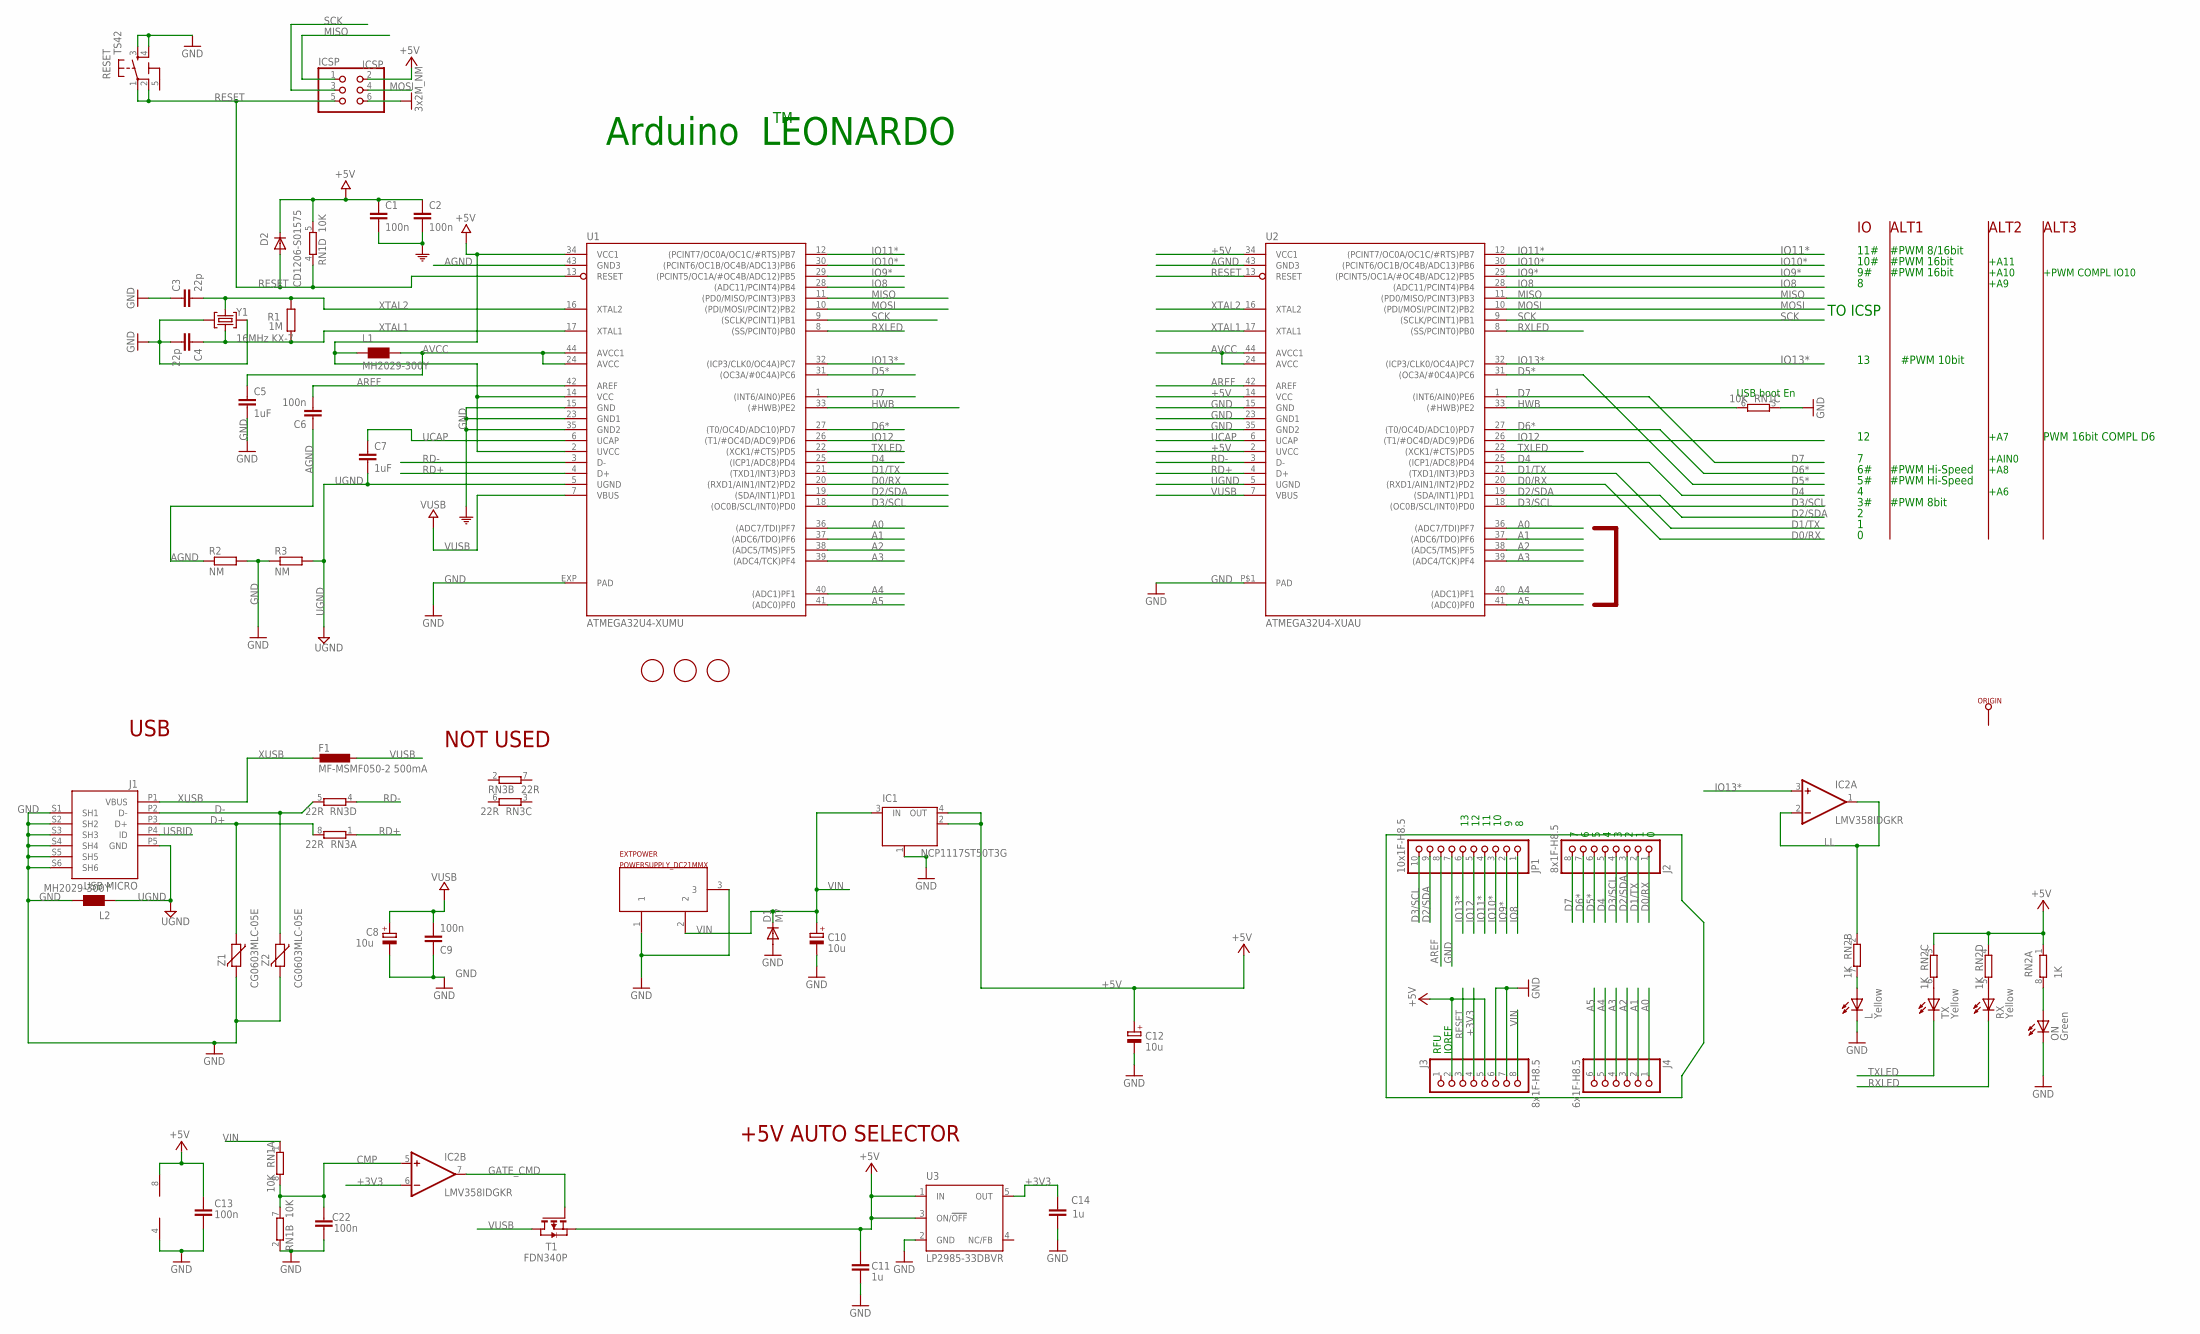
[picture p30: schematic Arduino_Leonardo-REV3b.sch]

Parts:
C1, C2, C6, C9, C13, C22: 100n; C0603-ROUND
C3, C4: 22p; C0603-ROUND
C5, C7: 1uF; C0603-ROUND
C8, C10, C12: 10u; SMC_B
C11, C14: 1u; C0603-ROUND
D1: M7; SMB
D2: CD1206-S01575; MINIMELF
EXTPOWER: POWERSUPPLY_DC21MMX; POWERSUPPLY_DC-21MM
F1: MF-MSMF050-2 500mA; L1812
FID1, FID2, FID3: FIDUCIALMOUNT; FIDUCIA-MOUNT
IC1: NCP1117ST50T3G; SOT223
IC2: LMV358IDGKR; MSOP08
ICSP: ICSP; 2X03
J1: USB MICRO; CON2_USB_MICRO_B_AT
J2, J3: 8x1F-H8.5; 1X08
J4: 6x1F-H8.5; 1X06
JP1: 10x1F-H8.5; 1X10
L: Yellow; CHIPLED_0805
L1, L2: MH2029-300Y; 0805
ON: Green; CHIPLED_0805
ORIGIN: TP_SP; TP-SP
R1: 1M; R0603-ROUND
R2, R3: NM; R0402
RESET: TS42
RN1: 10K; CAY16
RN2: 1K; CAY16
RN3: 22R; CAY16
RX: Yellow; CHIPLED_0805
T1: FDN340P; SOT-23
TX: Yellow; CHIPLED_0805
U1: ATMEGA32U4-XUMU; QFN44ML7X7
U2: ATMEGA32U4-XUAU; TQFP44-PAD
U3: LP2985-33DBVR; SOT23-DBV
Y1: 16MHz KX-7; CRYSTAL-3.2-2.5
Z1, Z2: CG0603MLC-05E; CT/CN0603

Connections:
5-GND: RESET.5 (5-GND)
+3V3: C14.2, IC2.6 (-IN), J3.4, U3.5 (OUT)
+5V: C1.1, C2.1, C11.2, C12.+, C13.1, D2.C, IC1.2 (OUT), IC1.4 (OUT), IC2.8 (V+), ICSP.2, J3.2, J3.5, L1.1, RN1.5 (2), RN2.1, RN2.3 (1), RN2.4 (1), T1.2 (S), U1.2 (UVCC), U1.14 (VCC), U1.34 (VCC1), U2.2 (UVCC), U2.14 (VCC), U2.34 (VCC1), U3.1 (IN), U3.3 (ON/!OFF)
A0: J4.1, U1.36 ((ADC7/TDI)PF7), U2.36 ((ADC7/TDI)PF7)
A1: J4.2, U1.37 ((ADC6/TDO)PF6), U2.37 ((ADC6/TDO)PF6)
A2: J4.3, U1.38 ((ADC5/TMS)PF5), U2.38 ((ADC5/TMS)PF5)
A3: J4.4, U1.39 ((ADC4/TCK)PF4), U2.39 ((ADC4/TCK)PF4)
A4: J4.5, U1.40 ((ADC1)PF1), U2.40 ((ADC1)PF1)
A5: J4.6, U1.41 ((ADC0)PF0), U2.41 ((ADC0)PF0)
AGND: C6.1, R2.1, U1.43 (GND3), U2.43 (GND3)
AREF: C6.2, JP1.8, U1.42 (AREF), U2.42 (AREF)
AVCC: C5.1, L1.2, U1.24 (AVCC), U1.44 (AVCC1), U2.24 (AVCC), U2.44 (AVCC1)
CMP: C22.2, IC2.5 (+IN), RN1.7 (2), RN1.8 (2)
D0/RX: J2.1, U1.20 ((RXD1/AIN1/INT2)PD2), U2.20 ((RXD1/AIN1/INT2)PD2)
D1/TX: J2.2, U1.21 ((TXD1/INT3)PD3), U2.21 ((TXD1/INT3)PD3)
D2/SDA: J2.3, JP1.9, U1.19 ((SDA/INT1)PD1), U2.19 ((SDA/INT1)PD1)
D3/SCL: J2.4, JP1.10, U1.18 ((OC0B/SCL/INT0)PD0), U2.18 ((OC0B/SCL/INT0)PD0)
D4: J2.5, U1.25 ((ICP1/ADC8)PD4), U2.25 ((ICP1/ADC8)PD4)
D5*: J2.6, U1.31 ((OC3A/#0C4A)PC6), U2.31 ((OC3A/#0C4A)PC6)
D6*: J2.7, U1.27 ((T0/OC4D/ADC10)PD7), U2.27 ((T0/OC4D/ADC10)PD7)
D7: J2.8, U1.1 ((INT6/AIN0)PE6), U2.1 ((INT6/AIN0)PE6)
D+: J1.P3 (D+), RN3.8 (2), Z1.1
D-: J1.P2 (D-), RN3.5 (2), Z2.1
GATE_CMD: IC2.7 (OUT), T1.3 (G)
GND: C1.2, C2.2, C3.1, C4.2, C5.2, C8.-, C9.1, C10.-, C11.1, C12.-, C13.2, C14.1, C22.1, D1.A, EXTPOWER.1, EXTPOWER.3, IC1.1 (GND/ADJ), IC2.4 (V-), ICSP.6, J1.S1 (SH1), J1.S2 (SH2), J1.S3 (SH3), J1.S4 (SH4), J1.S5 (SH5), J1.S6 (SH6), J3.6, J3.7, JP1.7, L.C, L2.2, ON.C, R2.2, R3.1, RESET.3, RESET.4, RN1.2 (1), RN1.3 (1), U1.15 (GND), U1.23 (GND1), U1.35 (GND2), U1.EXP (PAD), U2.15 (GND), U2.23 (GND1), U2.35 (GND2), U2.P$1 (PAD), U3.2 (GND), Y1.2 (GND), Y1.4 (GND), Z1.2, Z2.2
HWB: RN1.6 (2), U1.33 ((#HWB)PE2), U2.33 ((#HWB)PE2)
IO8: JP1.1, U1.28 ((ADC11/PCINT4)PB4), U2.28 ((ADC11/PCINT4)PB4)
IO9*: JP1.2, U1.29 ((PCINT5/OC1A/#OC4B/ADC12)PB5), U2.29 ((PCINT5/OC1A/#OC4B/ADC12)PB5)
IO10*: JP1.3, U1.30 ((PCINT6/OC1B/OC4B/ADC13)PB6), U2.30 ((PCINT6/OC1B/OC4B/ADC13)PB6)
IO11*: JP1.4, U1.12 ((PCINT7/OC0A/OC1C/#RTS)PB7), U2.12 ((PCINT7/OC0A/OC1C/#RTS)PB7)
IO12: JP1.5, U1.26 ((T1/#OC4D/ADC9)PD6), U2.26 ((T1/#OC4D/ADC9)PD6)
IO13*: IC2.3 (+IN), JP1.6, U1.32 ((ICP3/CLK0/OC4A)PC7), U2.32 ((ICP3/CLK0/OC4A)PC7)
LL: IC2.1 (OUT), IC2.2 (-IN), RN2.2 (1)
MISO: ICSP.1, U1.11 ((PD0/MISO/PCINT3)PB3), U2.11 ((PD0/MISO/PCINT3)PB3)
MOSI: ICSP.4, U1.10 ((PDI/MOSI/PCINT2)PB2), U2.10 ((PDI/MOSI/PCINT2)PB2)
unnamed: L.A, RN2.7 (2)
unnamed: ON.A, RN2.8 (2)
unnamed: RN2.6 (2), TX.A
unnamed: RN2.5 (2), RX.A
RD+: RN3.1, U1.4 (D+), U2.4 (D+)
RD-: RN3.4 (1), U1.3 (D-), U2.3 (D-)
RESET: D2.A, ICSP.5, J3.3, RESET.1, RESET.2, RN1.4 (1), U1.13 (RESET), U2.13 (RESET)
RXLED: RX.C, U1.8 ((SS/PCINT0)PB0), U2.8 ((SS/PCINT0)PB0)
SCK: ICSP.3, U1.9 ((SCLK/PCINT1)PB1), U2.9 ((SCLK/PCINT1)PB1)
TXLED: TX.C, U1.22 ((XCK1/#CTS)PD5), U2.22 ((XCK1/#CTS)PD5)
UCAP: C7.1, U1.6 (UCAP), U2.6 (UCAP)
UGND: C7.2, J1.P5 (GND), L2.1, R3.2, U1.5 (UGND), U2.5 (UGND)
USBID: J1.P4 (ID)
VIN: C10.+, D1.C, EXTPOWER.2, IC1.3 (IN), J3.8, RN1.1
VUSB: C8.+, C9.2, F1.1, T1.1 (D), U1.7 (VBUS), U2.7 (VBUS)
XTAL1: C4.1, R1.1, U1.17 (XTAL1), U2.17 (XTAL1), Y1.1 (C1)
XTAL2: C3.2, R1.2, U1.16 (XTAL2), U2.16 (XTAL2), Y1.3 (C2)
XUSB: F1.2, J1.P1 (VBUS)

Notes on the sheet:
Arduino LEONARDO
USB boot En
USB
+5V AUTO SELECTOR
NOT USED
TO ICSP
10#
11#
#PWM 8bit
#PWM Hi-Speed
#PWM 8/16bit
#PWM 16bit
PWM 16bit COMPL D6
#PWM 10bit
+A6
+A7
IOREF
RFU
+A11
+A10
+A8
+A9
+PWM COMPL IO10
+AIN0
ALT1
ALT2
ALT3

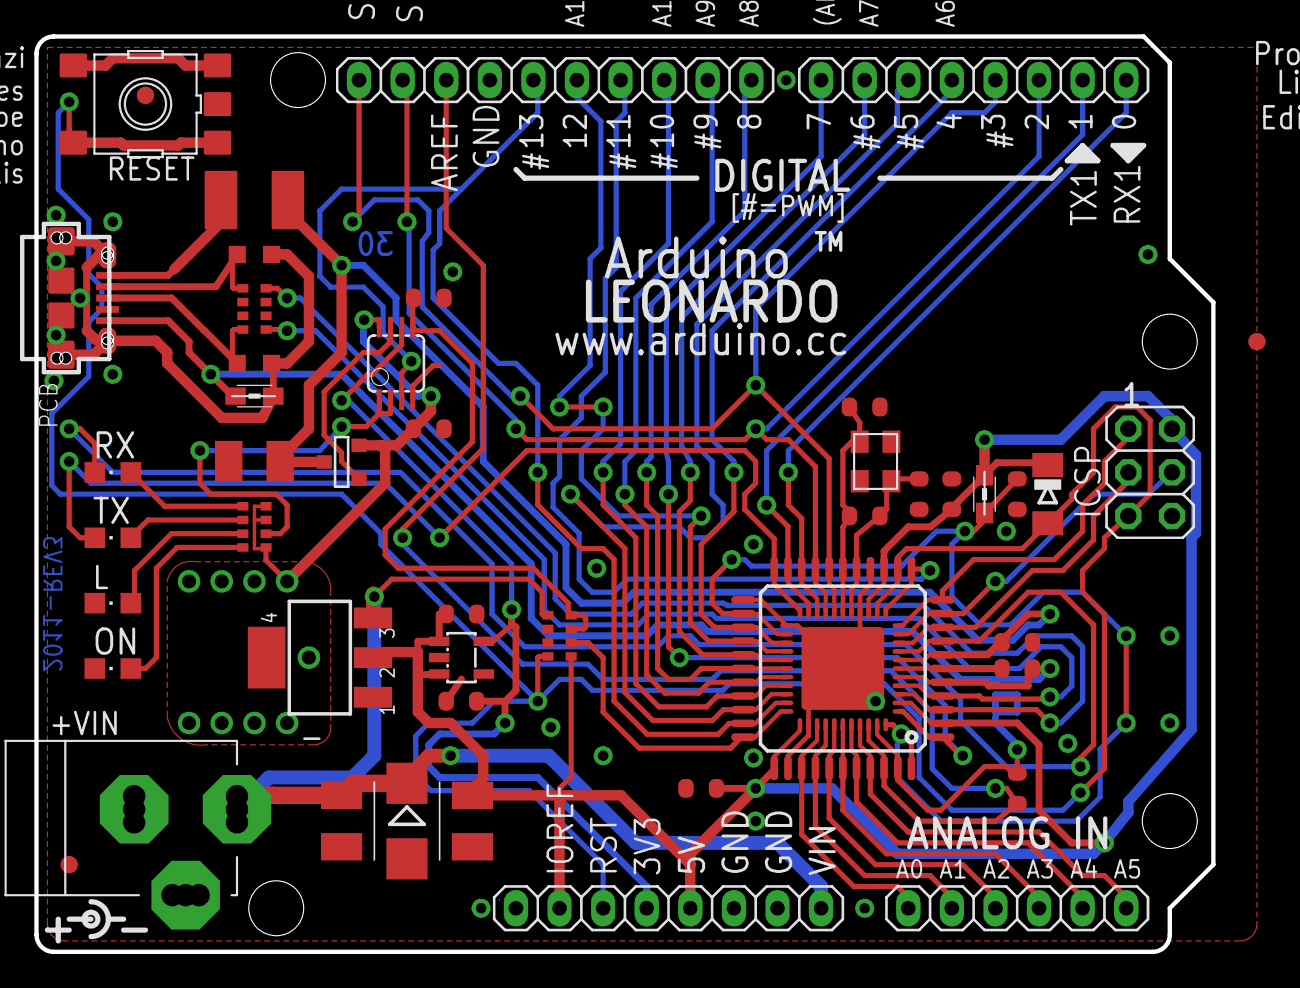
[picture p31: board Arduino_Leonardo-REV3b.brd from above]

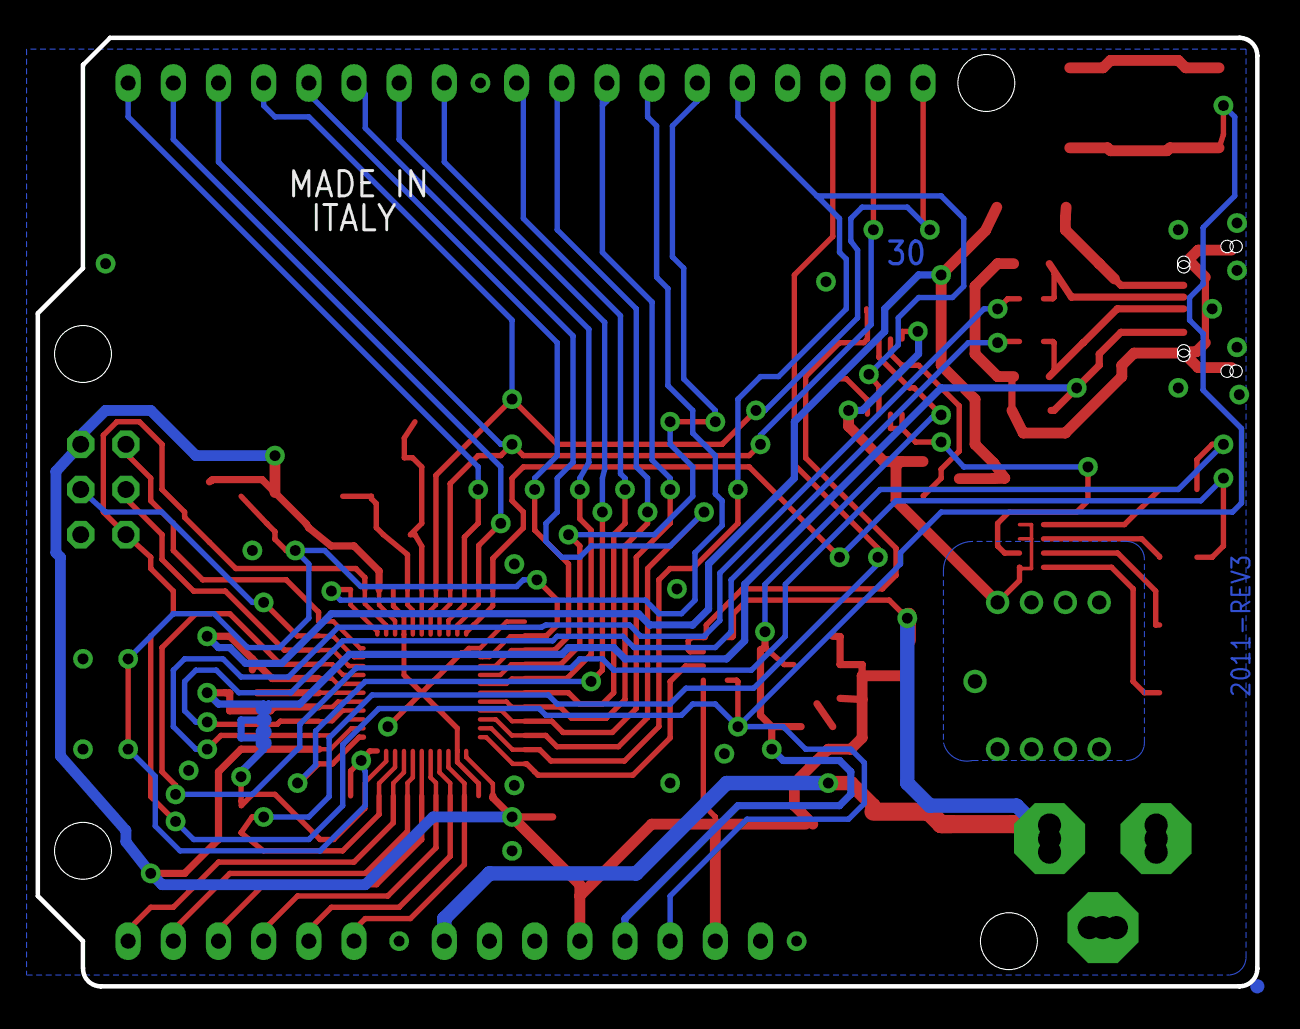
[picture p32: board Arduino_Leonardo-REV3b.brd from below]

Board: 2 copper layers, 68.6 x 53.3 mm, 51 parts (2 on the bottom side), 51 nets.

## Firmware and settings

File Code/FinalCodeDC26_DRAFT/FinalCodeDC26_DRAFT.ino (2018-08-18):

  /*****************************************************
 * B1un7 and the Flying Badgers DEFCON 26 Flying Skull
 * Code
 * WRitten by: B1un7
 * Date: Aug 10 2018
 *****************************************************
 *Sound f n Credit
 * Written by Brett Hagman
 * http://www.roguerobotics.com/
 * 
 *****************************************************
 *WS2812b Credit 
 *
 *****************************************************/

 //------------------- Includes ----------------------
#include <Adafruit_NeoPixel.h>


 //------------------- Constants ---------------------
const int tonePin = 5;  
int totalSongs = 4;
int currentSong = 0;
bool musicOn = false;
int totalEffects = 5;
int currentEffect = 2;
bool stayOn = false;       // KEEPO THE LIGHTING EFFECT ON


//--------------------- Defines ----------------------
#define OCTAVE_OFFSET 0

// These values can also be found as constants in the Tone library (Tone.h)
int notes[] = { 0,
262, 277, 294, 311, 330, 349, 370, 392, 415, 440, 466, 494,
523, 554, 587, 622, 659, 698, 740, 784, 831, 880, 932, 988,
1047, 1109, 1175, 1245, 1319, 1397, 1480, 1568, 1661, 1760, 1865, 1976,
2093, 2217, 2349, 2489, 2637, 2794, 2960, 3136, 3322, 3520, 3729, 3951
};

char* song[]={ // uncomment the tone you want to play when you push button 6 (far right) on Skull
"Scale:d=4,o=5,b=160:c,d,e,f,g,a,b",
//"The Simpsons:d=4,o=5,b=160:c.6,e6,f#6,8a6,g.6,e6,c6,8a,8f#,8f#,8f#,2g,8p,8p,8f#,8f#,8f#,8g,a#.,8c6,8c6,8c6,c6",
//"Indiana:d=4,o=5,b=250:e,8p,8f,8g,8p,1c6,8p.,d,8p,8e,1f,p.,g,8p,8a,8b,8p,1f6,p,a,8p,8b,2c6,2d6,2e6,e,8p,8f,8g,8p,1c6,p,d6,8p,8e6,1f.6,g,8p,8g,e.6,8p,d6,8p,8g,e.6,8p,d6,8p,8g,f.6,8p,e6,8p,8d6,2c6",
//"TakeOnMe:d=4,o=4,b=160:8f#5,8f#5,8f#5,8d5,8p,8b,8p,8e5,8p,8e5,8p,8e5,8g#5,8g#5,8a5,8b5,8a5,8a5,8a5,8e5,8p,8d5,8p,8f#5,8p,8f#5,8p,8f#5,8e5,8e5,8f#5,8e5,8f#5,8f#5,8f#5,8d5,8p,8b,8p,8e5,8p,8e5,8p,8e5,8g#5,8g#5,8a5,8b5,8a5,8a5,8a5,8e5,8p,8d5,8p,8f#5,8p,8f#5,8p,8f#5,8e5,8e5",
//"Entertainer:d=4,o=5,b=140:8d,8d#,8e,c6,8e,c6,8e,2c.6,8c6,8d6,8d#6,8e6,8c6,8d6,e6,8b,d6,2c6,p,8d,8d#,8e,c6,8e,c6,8e,2c.6,8p,8a,8g,8f#,8a,8c6,e6,8d6,8c6,8a,2d6"
//"Muppets:d=4,o=5,b=250:c6,c6,a,b,8a,b,g,p,c6,c6,a,8b,8a,8p,g.,p,e,e,g,f,8e,f,8c6,8c,8d,e,8e,8e,8p,8e,g,2p,c6,c6,a,b,8a,b,g,p,c6,c6,a,8b,a,g.,p,e,e,g,f,8e,f,8c6,8c,8d,e,8e,d,8d,c"
//"Xfiles:d=4,o=5,b=125:e,b,a,b,d6,2b.,1p,e,b,a,b,e6,2b.,1p,g6,f#6,e6,d6,e6,2b.,1p,g6,f#6,e6,d6,f#6,2b.,1p,e,b,a,b,d6,2b.,1p,e,b,a,b,e6,2b.,1p,e6,2b.",
//"Looney:d=4,o=5,b=140:32p,c6,8f6,8e6,8d6,8c6,a.,8c6,8f6,8e6,8d6,8d#6,e.6,8e6,8e6,8c6,8d6,8c6,8e6,8c6,8d6,8a,8c6,8g,8a#,8a,8f",
//"20thCenFox:d=16,o=5,b=140:b,8p,b,b,2b,p,c6,32p,b,32p,c6,32p,b,32p,c6,32p,b,8p,b,b,b,32p,b,32p,b,32p,b,32p,b,32p,b,32p,b,32p,g#,32p,a,32p,b,8p,b,b,2b,4p,8e,8g#,8b,1c#6,8f#,8a,8c#6,1e6,8a,8c#6,8e6,1e6,8b,8g#,8a,2b",
//"Bond:d=4,o=5,b=80:32p,16c#6,32d#6,32d#6,16d#6,8d#6,16c#6,16c#6,16c#6,16c#6,32e6,32e6,16e6,8e6,16d#6,16d#6,16d#6,16c#6,32d#6,32d#6,16d#6,8d#6,16c#6,16c#6,16c#6,16c#6,32e6,32e6,16e6,8e6,16d#6,16d6,16c#6,16c#7,c.7,16g#6,16f#6,g#.6",
//"MASH:d=8,o=5,b=140:4a,4g,f#,g,p,f#,p,g,p,f#,p,2e.,p,f#,e,4f#,e,f#,p,e,p,4d.,p,f#,4e,d,e,p,d,p,e,p,d,p,2c#.,p,d,c#,4d,c#,d,p,e,p,4f#,p,a,p,4b,a,b,p,a,p,b,p,2a.,4p,a,b,a,4b,a,b,p,2a.,a,4f#,a,b,p,d6,p,4e.6,d6,b,p,a,p,2b",
"StarWars:d=4,o=5,b=45:32p,32f#,32f#,32f#,8b.,8f#.6,32e6,32d#6,32c#6,8b.6,16f#.6,32e6,32d#6,32c#6,8b.6,16f#.6,32e6,32d#6,32e6,8c#.6,32f#,32f#,32f#,8b.,8f#.6,32e6,32d#6,32c#6,8b.6,16f#.6,32e6,32d#6,32c#6,8b.6,16f#.6,32e6,32d#6,32e6,8c#6",
//"GoodBad:d=4,o=5,b=56:32p,32a#,32d#6,32a#,32d#6,8a#.,16f#.,16g#.,d#,32a#,32d#6,32a#,32d#6,8a#.,16f#.,16g#.,c#6,32a#,32d#6,32a#,32d#6,8a#.,16f#.,32f.,32d#.,c#,32a#,32d#6,32a#,32d#6,8a#.,16g#.,d#"
//"TopGun:d=4,o=4,b=31:32p,16c#,16g#,16g#,32f#,32f,32f#,32f,16d#,16d#,32c#,32d#,16f,32d#,32f,16f#,32f,32c#,16f,d#,16c#,16g#,16g#,32f#,32f,32f#,32f,16d#,16d#,32c#,32d#,16f,32d#,32f,16f#,32f,32c#,g#"
"ATeam:d=8,o=5,b=125:4d#6,a#,2d#6,16p,g#,4a#,4d#.,p,16g,16a#,d#6,a#,f6,2d#6,16p,c#.6,16c6,16a#,g#.,2a#"
//"Flinstones:d=4,o=5,b=40:32p,16f6,16a#,16a#6,32g6,16f6,16a#.,16f6,32d#6,32d6,32d6,32d#6,32f6,16a#,16c6,d6,16f6,16a#.,16a#6,32g6,16f6,16a#.,32f6,32f6,32d#6,32d6,32d6,32d#6,32f6,16a#,16c6,a#,16a6,16d.6,16a#6,32a6,32a6,32g6,32f#6,32a6,8g6,16g6,16c.6,32a6,32a6,32g6,32g6,32f6,32e6,32g6,8f6,16f6,16a#.,16a#6,32g6,16f6,16a#.,16f6,32d#6,32d6,32d6,32d#6,32f6,16a#,16c.6,32d6,32d#6,32f6,16a#,16c.6,32d6,32d#6,32f6,16a#6,16c7,8a#.6",
//"Jeopardy:d=4,o=6,b=125:c,f,c,f5,c,f,2c,c,f,c,f,a.,8g,8f,8e,8d,8c#,c,f,c,f5,c,f,2c,f.,8d,c,a#5,a5,g5,f5,p,d#,g#,d#,g#5,d#,g#,2d#,d#,g#,d#,g#,c.7,8a#,8g#,8g,8f,8e,d#,g#,d#,g#5,d#,g#,2d#,g#.,8f,d#,c#,c,p,a#5,p,g#.5,d#,g#",
//"Gadget:d=16,o=5,b=50:32d#,32f,32f#,32g#,a#,f#,a,f,g#,f#,32d#,32f,32f#,32g#,a#,d#6,4d6,32d#,32f,32f#,32g#,a#,f#,a,f,g#,f#,8d#",
//"Smurfs:d=32,o=5,b=200:4c#6,16p,4f#6,p,16c#6,p,8d#6,p,8b,p,4g#,16p,4c#6,p,16a#,p,8f#,p,8a#,p,4g#,4p,g#,p,a#,p,b,p,c6,p,4c#6,16p,4f#6,p,16c#6,p,8d#6,p,8b,p,4g#,16p,4c#6,p,16a#,p,8b,p,8f,p,4f#",
"MahnaMahna:d=16,o=6,b=125:c#,c.,b5,8a#.5,8f.,4g#,a#,g.,4d#,8p,c#,c.,b5,8a#.5,8f.,g#.,8a#.,4g,8p,c#,c.,b5,8a#.5,8f.,4g#,f,g.,8d#.,f,g.,8d#.,f,8g,8d#.,f,8g,d#,8c,a#5,8d#.,8d#.,4d#,8d#.",
//"LeisureSuit:d=16,o=6,b=56:f.5,f#.5,g.5,g#5,32a#5,f5,g#.5,a#.5,32f5,g#5,32a#5,g#5,8c#.,a#5,32c#,a5,a#.5,c#.,32a5,a#5,32c#,d#,8e,c#.,f.,f.,f.,f.,f,32e,d#,8d,a#.5,e,32f,e,32f,c#"//,d#.,c#",
"MissionImp:d=16,o=6,b=95:32d,32d#,32d,32d#,32d,32d#,32d,32d#,32d,32d,32d#,32e,32f,32f#,32g,g,8p,g,8p,a#,p,c7,p,g,8p,g,8p,f,p,f#,p,g,8p,g,8p,a#,p,c7,p,g,8p,g,8p,f,p,f#,p,a#,g,2d,32p,a#,g,2c#,32p,a#,g,2c,a#5,8c,2p,32p,a#5,g5,2f#,32p,a#5,g5,2f,32p,a#5,g5,2e,d#,8d"
};

#define isdigit(n) (n >= '0' && n <= '9') //From Sound Program

#define PIN 4 // for WS2812b LEDs
Adafruit_NeoPixel strip = Adafruit_NeoPixel(16, PIN, NEO_GRB);


//---------------------- Setup ------------------------
 
void setup() {
  // put your setup code here, to run once:

  Serial.begin(9600);
  pinMode(14, INPUT_PULLUP);
  play_rtttl(song[0]); //part of POST test
  int totalSongs = 4;
  int currentSong = 0;
  bool musicOn = false;

  strip.begin(); // Initalize RGB WS2812b string
  strip.show(); // Initialize all pixels to 'off'
  startUp();
  colorWipe(strip.Color(0, 0, 0), 1); //off
  strip.show(); // Initialize all pixels to 'off'
}

//----------------- Funtion Definitions ----------------

//+++++++++++++++++++ Play RTTTL +++++++++++++++++++++++
void play_rtttl(char *p)
{
  // Absolutely no error checking in here

  byte default_dur = 4;
  byte default_oct = 6;
  int bpm = 63;
  int num;
  long wholenote;
  long duration;
  byte note;
  byte scale;

  // format: d=N,o=N,b=NNN:
  // find the start (skip name, etc)

  while(*p != ':') p++;    // ignore name
  p++;                     // skip ':'

  // get default duration
  if(*p == 'd')
  {
    p++; p++;              // skip "d="
    num = 0;
    while(isdigit(*p))
    {
      num = (num * 10) + (*p++ - '0');
    }
    if(num > 0) default_dur = num;
    p++;                   // skip comma
  }

  // get default octave
  if(*p == 'o')
  {
    p++; p++;              // skip "o="
    num = *p++ - '0';
    if(num >= 3 && num <=7) default_oct = num;
    p++;                   // skip comma
  }
  
  // get BPM
  if(*p == 'b')
  {
    p++; p++;              // skip "b="
    num = 0;
    while(isdigit(*p))
    {
      num = (num * 10) + (*p++ - '0');
    }
    bpm = num;
    p++;                   // skip colon
  }

  // BPM usually expresses the number of quarter notes per minute
  wholenote = (60 * 1000L / bpm) * 4;  // this is the time for whole note (in milliseconds)

// now begin note loop
  while(*p) //while there are notes still to play in the song stored in char *p

  {
    // first, get note duration, if available
    num = 0;
    while(isdigit(*p))
    {
      num = (num * 10) + (*p++ - '0');
    }
   
    if(num) duration = wholenote / num;
    else duration = wholenote / default_dur;  // we will need to check if we are a dotted note after

    // now get the note
    note = 0;

    switch(*p)
    {
      case 'c':
        note = 1;
        break;
      case 'd':
        note = 3;
        break;
      case 'e':
        note = 5;
        break;
      case 'f':
        note = 6;
        break;
      case 'g':
        note = 8;
        break;
      case 'a':
        note = 10;
        break;
      case 'b':
        note = 12;
        break;
      case 'p':
      default:
        note = 0;
    }
    p++;

    // now, get optional '#' sharp
    if(*p == '#')
    {
      note++;
      p++;
    }

    // now, get optional '.' dotted note
    if(*p == '.')
    {
      duration += duration/2;
      p++;
    }
 
    // now, get scale
    if(isdigit(*p))
    {
      scale = *p - '0';
      p++;
    }
    else
    {
      scale = default_oct;
    }

    scale += OCTAVE_OFFSET;

    if(*p == ',')
      p++;       // skip comma for next note (or we may be at the end)

    // now play the note

    if(note)
    {
      tone(tonePin, notes[(scale - 4) * 12 + note]);
      delay(duration);
      noTone(tonePin);
    }
    else
    {
      delay(duration);
    }
  }
}


//+++++++++++++++++++++ LEDs +++++++++++++++++++++
// Fill the dots one after the other with a color
void startUp() {
  colorWipe(strip.Color(255, 0, 0), 50); // Red
  strip.show(); // Initialize all pixels to 'off'
  delay(1000);
  colorWipe(strip.Color(0, 255, 0), 50); // Green
  strip.show(); // Initialize all pixels to 'off'
  delay(1000);
  colorWipe(strip.Color(0, 0, 255), 50); // Blue
  strip.show(); // Initialize all pixels to 'off'
  delay(1000); 
}


// Fill the dots one after the other with a color
void colorWipe(uint32_t c, uint8_t wait) {
  for(uint16_t i=0; i<strip.numPixels(); i++) {
    strip.setPixelColor(i, c);
    strip.show();
    delay(wait);
  }
}

void slowChase(uint8_t wait) {
  uint16_t i;

  for(i=0; i<strip.numPixels(); i++) {
    strip.setPixelColor(i-3, 0,0,0);
    strip.setPixelColor(i-2, 127,127,127);
    strip.setPixelColor(i-1, 127, 127, 127);
    strip.setPixelColor(i, 0,0,255);
    strip.show();

    delay(500);
  }
  strip.show();
  delay(wait);
}

void rainbow(uint8_t wait) {
  uint16_t i, j;

  for(j=0; j<256; j++) {
    for(i=0; i<strip.numPixels(); i++) {
      strip.setPixelColor(i, Wheel((i+j) & 255));
    }
    strip.show();
    delay(wait);
  }
}

// Slightly different, this makes the rainbow equally distributed throughout
void rainbowCycle(uint8_t wait) {
  uint16_t i, j;

  for(j=0; j<256*5; j++) { // 5 cycles of all colors on wheel
    for(i=0; i< strip.numPixels(); i++) {
      strip.setPixelColor(i, Wheel(((i * 256 / strip.numPixels()) + j) & 255));
    }
    strip.show();
    delay(wait);
  }
}

//Theatre-style crawling lights.
void theaterChase(uint32_t c, uint8_t wait) {
  for (int j=0; j<10; j++) {  //do 10 cycles of chasing
    for (int q=0; q < 3; q++) {
      for (uint16_t i=0; i < strip.numPixels(); i=i+3) {
        strip.setPixelColor(i+q, c);    //turn every third pixel on
      }
      strip.show();

      delay(wait);

      for (uint16_t i=0; i < strip.numPixels(); i=i+3) {
        strip.setPixelColor(i+q, 0);        //turn every third pixel off
      }
    }
  }
}

//+++++++++++++++++ slowChase LEDs +++++++++++++++++++++
void slowChase()
{
  colorWipe(strip.Color(255, 0, 0), 50); // Red
  strip.show(); // Initialize all pixels to 'off'
  delay(2000);
  colorWipe(strip.Color(0, 255, 0), 50); // Green
  strip.show(); // Initialize all pixels to 'off'
  delay(2000);
  colorWipe(strip.Color(0, 0, 255), 50); // Blue
  strip.show(); // Initialize all pixels to 'off'
  delay(2000);
  strip.show(); // Initialize all pixels to 'off'

}


// Input a value 0 to 255 to get a color value.
// The colours are a transition r - g - b - back to r.
uint32_t Wheel(byte WheelPos) {
  WheelPos = 255 - WheelPos;
  if(WheelPos < 85) {
    return strip.Color(255 - WheelPos * 3, 0, WheelPos * 3);
  }
  if(WheelPos < 170) {
    WheelPos -= 85;
    return strip.Color(0, WheelPos * 3, 255 - WheelPos * 3);
  }
  WheelPos -= 170;
  return strip.Color(WheelPos * 3, 255 - WheelPos * 3, 0);
}

//Theatre-style crawling lights with rainbow effect
void theaterChaseRainbow(uint8_t wait) {
  for (int j=0; j < 256; j++) {     // cycle all 256 colors in the wheel
    for (int q=0; q < 3; q++) {
      for (uint16_t i=0; i < strip.numPixels(); i=i+3) {
        strip.setPixelColor(i+q, Wheel( (i+j) % 255));    //turn every third pixel on
      }
      strip.show();

      delay(wait);

      for (uint16_t i=0; i < strip.numPixels(); i=i+3) {
        strip.setPixelColor(i+q, 0);        //turn every third pixel off
      }
    }
  }
}

//------------------- Main Loop ---------------------

void loop() {
  strip.show(); // Initialize all pixels to 'off'
  int teethButtons = analogRead(A0);
  int tButton = map((teethButtons+50), 0, 900, 0, 6); //+
  Serial.println(tButton);
  if (tButton == 6) {
    play_rtttl(song[currentSong]);
  }
  if (tButton == 5) {
    if (currentSong == totalSongs){
      currentSong = -1;
    }
    currentSong = currentSong + 1;
    delay(1000);
  }
  if ((tButton == 4) or (stayOn == true)) {
    if ((tButton == 4) and (currentEffect == 5)) {
      currentEffect=0;
    }
    if (currentEffect == 0) {
      startUp();
      colorWipe(strip.Color(0, 0, 0), 1); //off
      strip.show(); // Initialize all pixels to 'off'
    }
    if (currentEffect == 1) {
      slowChase();
      colorWipe(strip.Color(0, 0, 0), 1); //off
      strip.show(); // Initialize all pixels to 'off'
    }
    if (currentEffect == 2) {
      rainbow(20);
      colorWipe(strip.Color(0, 0, 0), 1); //off
      strip.show(); // Initialize all pixels to 'off'
    }
    if (currentEffect == 3) {
      rainbowCycle(20);
      colorWipe(strip.Color(0, 0, 0), 1); //off
      strip.show(); // Initialize all pixels to 'off'
    }
    if (currentEffect == 4) {
      theaterChase(strip.Color(127, 127, 127), 50); // White
      strip.show(); // Initialize all pixels to 'off'
      delay(2000);
      theaterChase(strip.Color(127, 0, 0), 50); // Red
      strip.show(); // Initialize all pixels to 'off'
      delay(2000);
      theaterChase(strip.Color(0, 0, 127), 50); // Blue
      strip.show(); // Initialize all pixels to 'off'
      delay(2000);
    }
    if (currentEffect == 5) {
      theaterChaseRainbow(50);
      colorWipe(strip.Color(0, 0, 0), 1); //off
      strip.show(); // Initialize all pixels to 'off'
    }
  }

  if (tButton == 3) {
    if (currentEffect == totalEffects)
    {
      currentEffect = -1;
    }  
    currentEffect = currentEffect + 1;
    delay(1000);

  }
  
}

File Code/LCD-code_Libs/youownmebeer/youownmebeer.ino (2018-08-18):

/***************************************************
  This is our GFX example for the Adafruit ILI9341 Breakout and Shield
  ----> http://www.adafruit.com/products/1651

  Check out the links above for our tutorials and wiring diagrams
  These displays use SPI to communicate, 4 or 5 pins are required to
  interface (RST is optional)
  Adafruit invests time and resources providing this open source code,
  please support Adafruit and open-source hardware by purchasing
  products from Adafruit!

  Written by Limor Fried/Ladyada for Adafruit Industries.
  MIT license, all text above must be included in any redistribution
 ****************************************************/


#include <SPI.h>
#include <ILI9341_due_config.h>
#include <ILI9341_due.h>
#include <SystemFont5x7.h>
#include <Adafruit_NeoPixel.h>

#define TFT_RST 8
#define TFT_DC 9
#define TFT_CS 10
#define PIN 4

Adafruit_NeoPixel strip = Adafruit_NeoPixel(4, PIN, NEO_GRB + NEO_KHZ800);

// Use hardware SPI (on Uno, #13, #12, #11) and the above for CS/DC
ILI9341_due tft = ILI9341_due(TFT_CS, TFT_DC, TFT_RST);

void setup() {
  Serial.begin(9600);
  while (!Serial) ; // wait for Arduino Serial Monitor
  Serial.println(F("ILI9341 Test!")); 
  strip.begin();
  strip.show(); // Initialize all pixels to 'off'
  tft.begin();

  // read diagnostics (optional but can help debug problems)
  uint8_t x = tft.readcommand8(ILI9341_RDMODE);
  Serial.print(F("Display Power Mode: 0x")); Serial.println(x, HEX);
  x = tft.readcommand8(ILI9341_RDMADCTL);
  Serial.print(F("MADCTL Mode: 0x")); Serial.println(x, HEX);
  x = tft.readcommand8(ILI9341_RDPIXFMT);
  Serial.print(F("Pixel Format: 0x")); Serial.println(x, HEX);
  x = tft.readcommand8(ILI9341_RDIMGFMT);
  Serial.print(F("Image Format: 0x")); Serial.println(x, HEX);
  x = tft.readcommand8(ILI9341_RDSELFDIAG);
  Serial.print(F("Self Diagnostic: 0x")); Serial.println(x, HEX); 
  
  Serial.println(F("Benchmark                Time (microseconds)"));

//  Serial.print(F("Screen fill              "));
//  Serial.println(testFillScreen());
//  delay(200);
//
//  Serial.print(F("Text                     "));
//  Serial.println(testText());
//  delay(600);
//
//  Serial.print(F("Lines                    "));
//  Serial.println(testLines(ILI9341_CYAN));
//  delay(200);
//
//  Serial.print(F("Horiz/Vert Lines         "));
//  Serial.println(testFastLines(ILI9341_RED, ILI9341_BLUE));
//  delay(200);
//
//  Serial.print(F("Rectangles (outline)     "));
//  Serial.println(testRects(ILI9341_GREEN));
//  delay(200);
//
//  Serial.print(F("Rectangles (filled)      "));
//  Serial.println(testFilledRects(ILI9341_YELLOW, ILI9341_MAGENTA));
//  delay(200);
//
//  Serial.print(F("Circles (filled)         "));
//  Serial.println(testFilledCircles(10, ILI9341_MAGENTA));
//
//  Serial.print(F("Circles (outline)        "));
//  Serial.println(testCircles(10, ILI9341_WHITE));
//  delay(200);
//
//  Serial.print(F("Triangles (outline)      "));
//  Serial.println(testTriangles());
//  delay(200);
//
//  Serial.print(F("Triangles (filled)       "));
//  Serial.println(testFilledTriangles());
//  delay(200);
//
//  Serial.print(F("Rounded rects (outline)  "));
//  Serial.println(testRoundRects());
//  delay(200);
//
//  Serial.print(F("Rounded rects (filled)   "));
//  Serial.println(testFilledRoundRects());
//  delay(200);

  Serial.println(F("Done!"));

}


void loop(void) {
  for(uint8_t rotation=0; rotation<4; rotation++) {
    tft.setRotation((iliRotation)rotation);
    testText();
    delay(1000);
  }
  rainbow(20);
}
void rainbow(uint8_t wait) {
  uint16_t i, j;

  for(j=0; j<256; j++) {
    for(i=0; i<strip.numPixels(); i++) {
      strip.setPixelColor(i, Wheel((i+j) & 255));
    }
    strip.show();
    delay(wait);
  }
}


// Input a value 0 to 255 to get a color value.
// The colours are a transition r - g - b - back to r.
uint32_t Wheel(byte WheelPos) {
  WheelPos = 255 - WheelPos;
  if(WheelPos < 85) {
    return strip.Color(255 - WheelPos * 3, 0, WheelPos * 3);
  }
  if(WheelPos < 170) {
    WheelPos -= 85;
    return strip.Color(0, WheelPos * 3, 255 - WheelPos * 3);
  }
  WheelPos -= 170;
  return strip.Color(WheelPos * 3, 255 - WheelPos * 3, 0);
}

unsigned long testFillScreen() {
  unsigned long start = micros();
  //tft.fillScreen(ILI9341_BLACK);
  tft.fillScreen(ILI9341_RED);
  //tft.fillScreen(ILI9341_GREEN);
  //tft.fillScreen(ILI9341_BLUE);
  //tft.fillScreen(ILI9341_BLACK);
  return micros() - start;
}

unsigned long testText() {
  tft.fillScreen(ILI9341_BLACK);
  unsigned long start = micros();
  tft.cursorTo(0, 0);
  tft.setFont(SystemFont5x7);
  tft.setTextColor(ILI9341_WHITE);  tft.setTextScale(1);
  tft.println("Hello World!");
  tft.setTextColor(ILI9341_YELLOW); tft.setTextScale(2);
  tft.println(1234.56);
  tft.setTextColor(ILI9341_RED);    tft.setTextScale(3);
  tft.println(0xDEADBEEF, HEX);
  tft.println();
  tft.setTextColor(ILI9341_GREEN);
  tft.setTextScale(5);
  tft.println("Groop");
  tft.setTextScale(2);
  tft.println("I implore thee,");
  tft.setTextScale(1);
  tft.println("my foonting turlingdromes.");
  tft.println("And hooptiously drangle me");
  tft.println("with crinkly bindlewurdles,");
  tft.println("Or I will rend thee");
  tft.println("in the gobberwarts");
  tft.println("with my blurglecruncheon,");
  tft.println("see if I don't!");
  return micros() - start;
}


unsigned long testText_1() {
  tft.fillScreen(ILI9341_BLACK);
  unsigned long start = micros();
  tft.cursorTo(0, 10);
  tft.setFont(SystemFont5x7);
//  tft.setTextColor(ILI9341_WHITE);  tft.setTextScale(1);
//  tft.println("Hello World!");
//  tft.setTextColor(ILI9341_YELLOW); tft.setTextScale(2);
//  tft.println(1234.56);
  tft.setTextColor(ILI9341_RED);    tft.setTextScale(2);
  tft.println("You sir, own me a beer!");
  tft.println();
//  tft.setTextColor(ILI9341_GREEN);
//  tft.setTextScale(5);
//  tft.println("Groop");
//  tft.setTextScale(2);
//  tft.println("I implore thee,");
//  tft.setTextScale(1);
//  tft.println("my foonting turlingdromes.");
//  tft.println("And hooptiously drangle me");
//  tft.println("with crinkly bindlewurdles,");
//  tft.println("Or I will rend thee");
//  tft.println("in the gobberwarts");
//  tft.println("with my blurglecruncheon,");
//  tft.println("see if I don't!");
  return micros() - start;
}
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

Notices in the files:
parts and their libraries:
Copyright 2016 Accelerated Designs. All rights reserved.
